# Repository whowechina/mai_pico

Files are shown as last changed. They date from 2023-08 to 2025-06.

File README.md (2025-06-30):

# Mai Pico - Maimai Style Mini Controller
[点这里可以切换到中文版](README_CN.md)

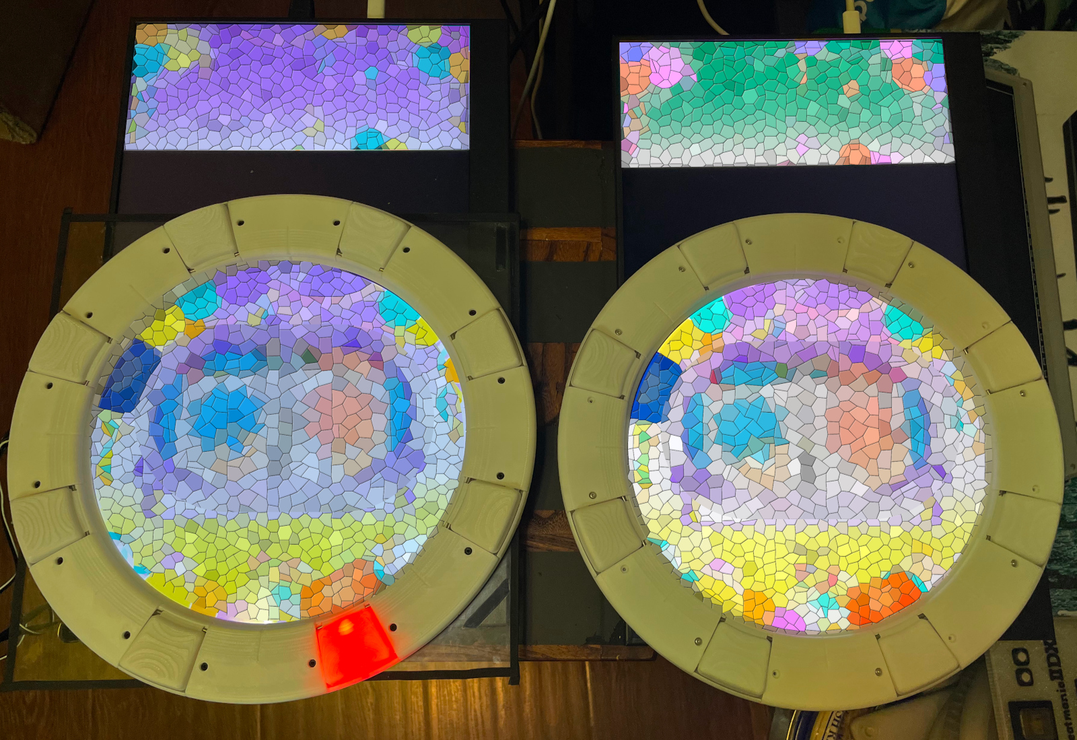
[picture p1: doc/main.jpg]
  
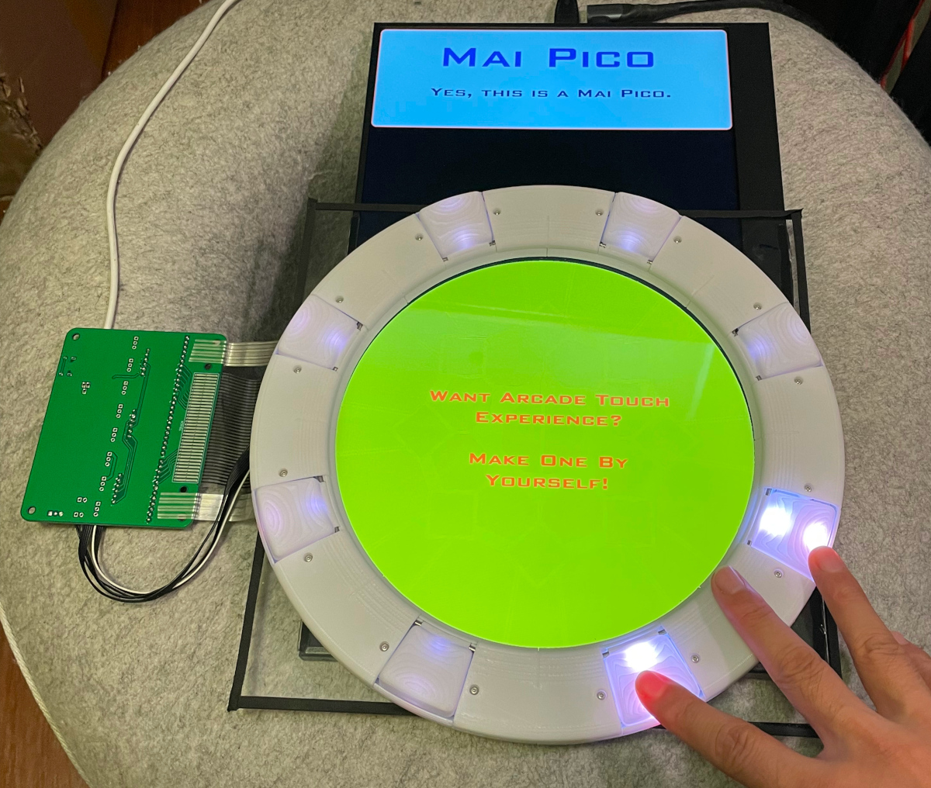
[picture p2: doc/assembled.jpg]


**Features:**
* Made with a 15.6 inch portable screen.
* Arcade-like experience.
* Dual-player is possible.
* Built-in AIME support.
* All source files open.

Thanks to many respectful guys/companies who made their tools or materials free or open source (KiCad, OnShape, InkScape, Raspberry things, JLCPCB), and also:
* RP_Silicon_KiCad: https://github.com/HeadBoffin/RP_Silicon_KiCad
* Switch_Keyboard_Kailh: https://github.com/kiswitch/keyswitch-kicad-library
* Type-C: https://github.com/ai03-2725/Type-C.pretty
* Mai2Touch: https://github.com/Sucareto/Mai2Touch

## Notes
This project is the most complex one among all my projects.
* It needs a custom etched ITO glass and a portable display.
* Heavily depends on 3D printing.
* Requires skills to solder tiny components.
* Requires many other DIY hands-on skills.
* The IO PCB is still in prototype state, it works, but the layout and connectors are not perfect. You may need to solder directly from Pi Pico's pins. I'm just too lazy to release a new version.
* I didn't design the housing, so it's your job to make it look nice and structually stable, follow your imagination and taste.

## About the License
It's CC-NC. So DIY for yourself and for your friend for free, don't make money from it. And plagiarism that doesn’t even dare to mention the original author is not acceptable. Plase note that pooling orders and group buying for raw materials is acceptable. Selling off any leftover components without profit is also acceptable.

If you're interested in buying from me or some kind of commercial use, please contact me (Discord, QQ group, Wechat group or leave your contact in issue section).

## My Discord Invitation
https://discord.gg/M8f2PPQFEA

## My Other Projects
You can check out my other cool projects.

             

* Popn Pico: https://github.com/whowechina/popn_pico
* IIDX Pico: https://github.com/whowechina/iidx_pico
* IIDX Teeny: https://github.com/whowechina/iidx_teeny
* Chu Pico: https://github.com/whowechina/chu_pico
* Mai Pico: https://github.com/whowechina/mai_pico
* Diva Pico: https://github.com/whowechina/diva_pico
* AIC Pico: https://github.com/whowechina/aic_pico
* Groove Pico: https://github.com/whowechina/groove_pico
* Geki Pico: https://github.com/whowechina/geki_pico
* Musec Pico: https://github.com/whowechina/musec_pico
* Ju Pico: https://github.com/whowechina/ju_pico
* Bishi Pico: https://github.com/whowechina/bishi_pico
* Bishi Pico: https://github.com/whowechina/nos_pico

## **Disclaimer** ##
I made this project in my personal time without any sponsorship. I will continue to improve the project. I have done my best to ensure that everything is accurate and functional, there's always a chance that mistakes may occur. I cannot be held responsible for any loss of your time or money that may result from using this open source project. Thank you for your understanding.

## Builds Gallery
Before we start, I want to encourage you with some hobbyist builds.

### **Lavide's Build**
  Lavide made a nice compact all-in-one Mai Pico cab!  
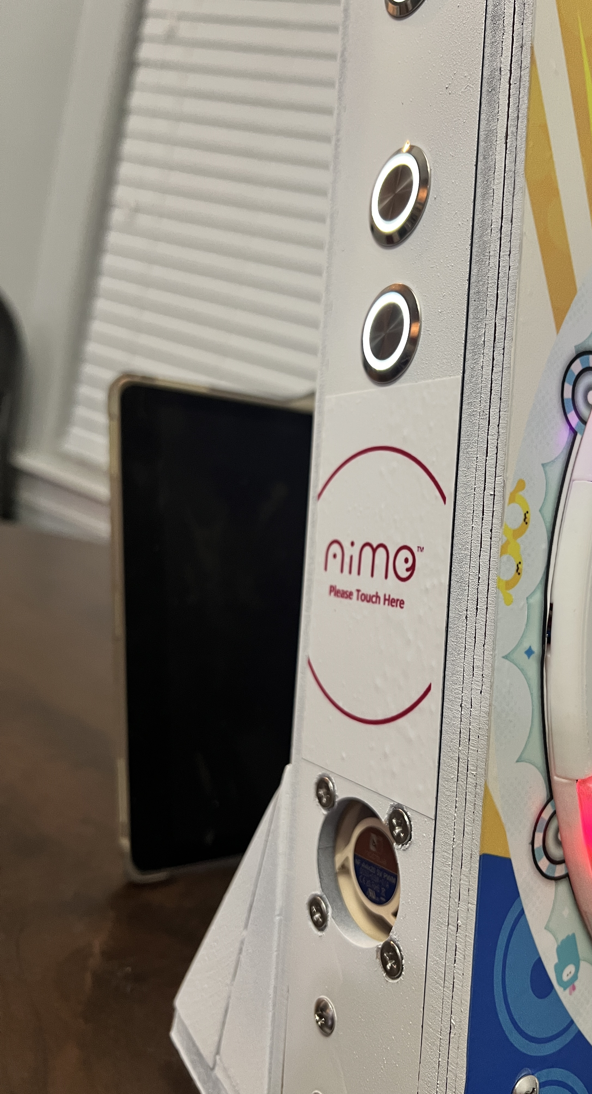
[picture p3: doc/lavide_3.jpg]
  

### **Romper's Build**
  Romper made a full-size con using Mai Pico's touch design.  
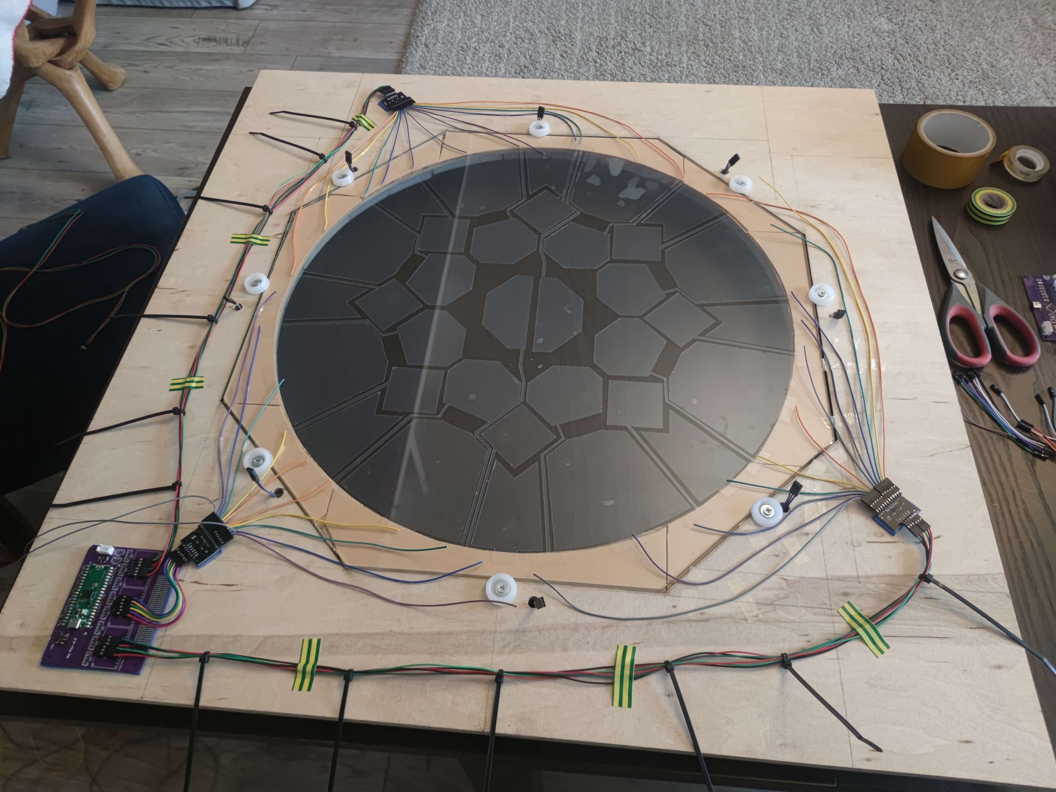
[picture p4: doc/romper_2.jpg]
    
  Check out his build guide here.  
  https://github.com/ir0nq/maimai-homemade-controller

### **imfrea's Build**
  imfrea designed a nice-looking and inexpensive acrylic housing for Mai Pico.  
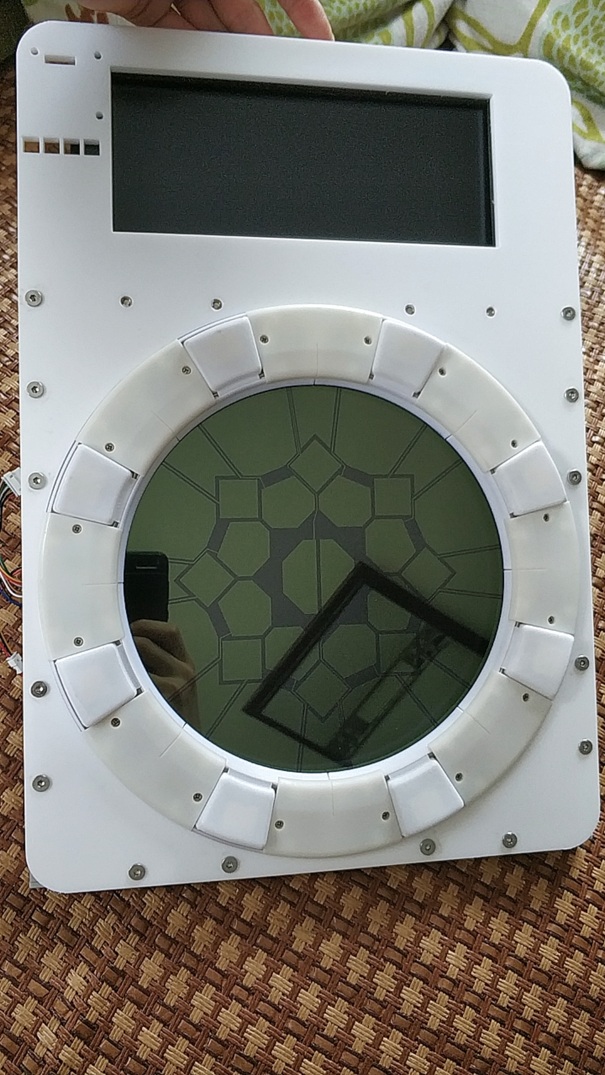
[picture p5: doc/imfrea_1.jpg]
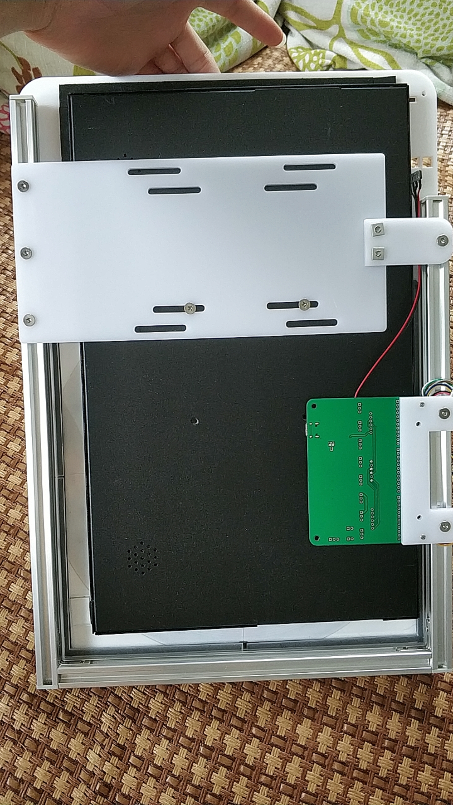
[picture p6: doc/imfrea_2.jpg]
    
  You can download the acrylic case designs from his fork of Mai Pico here.  
  https://github.com/imfrea/mai_pico

### ***IlIIllllIlIIlll's Build**
  IlIIllllIlIIlll made another nice and compact housing.  
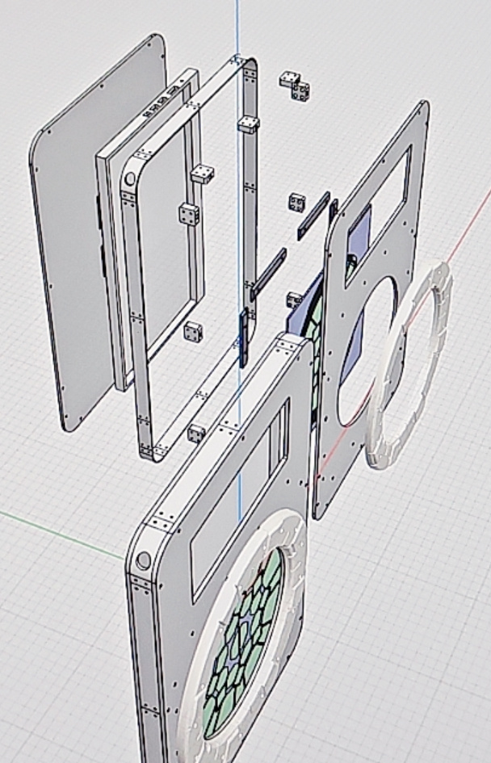
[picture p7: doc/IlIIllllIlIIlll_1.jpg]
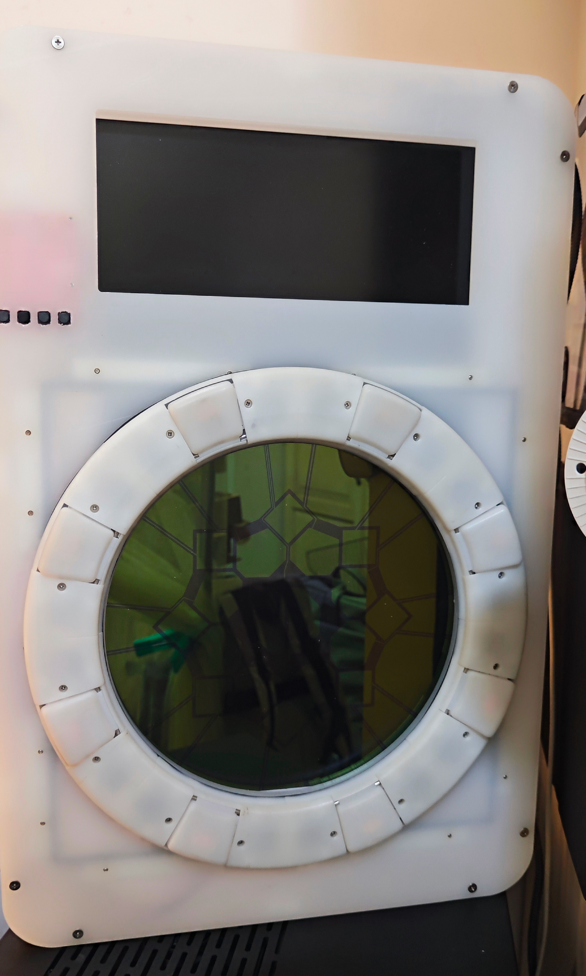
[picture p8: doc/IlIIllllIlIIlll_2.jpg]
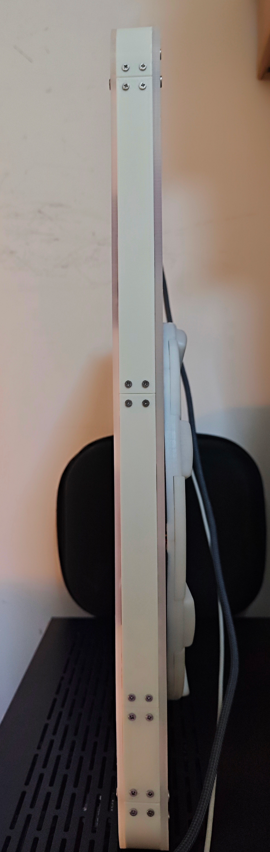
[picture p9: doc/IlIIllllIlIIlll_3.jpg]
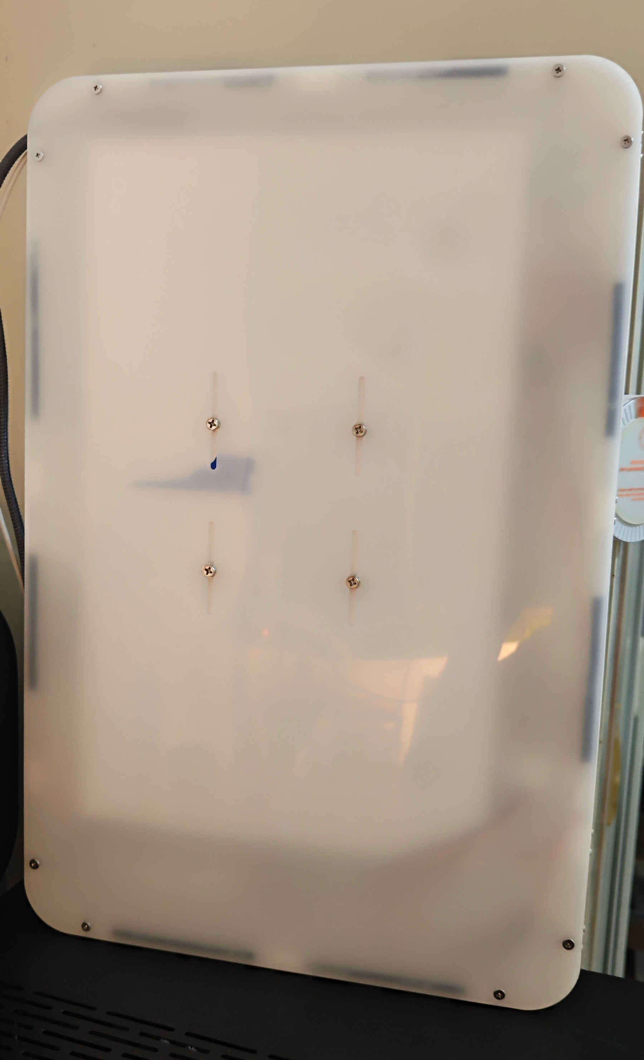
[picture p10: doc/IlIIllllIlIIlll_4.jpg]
       
  Thanks to his/her contribution, you can download the design files directly from this repository. It's located at `Production\3rdparty\IlIIllllIlIIlll_housing.zip`. The panel can be cut from PP or acrylic sheets, and other parts can be 3D printed. Plase note that this design is also not for commercial use.

## HOW TO BUILD
### PCB
* Go JLCPCB and make order with the gerber zip file (latest `Production\PCB\mai_io_v*.zip` and `Production\PCB\mai_button_v*.zip`), regular FR-4 board, 1.6mm thickness. You need 1x io PCB and 8x button PCBs for one Mai Pico con.  
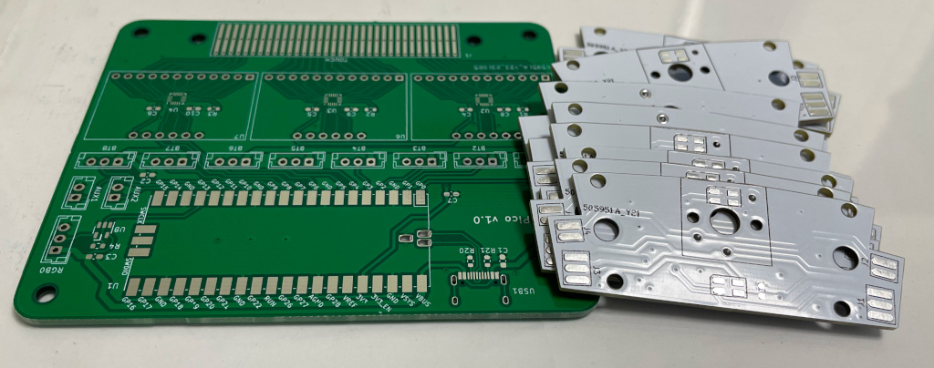
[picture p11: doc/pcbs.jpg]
  
* 1x Rasberry Pico Pi Pico or Pico W.  
  https://www.raspberrypi.com/products/raspberry-pi-pico
  Becareful of 3 pins that are at the other side, they're difficult to solder and may leave air bubbles.  
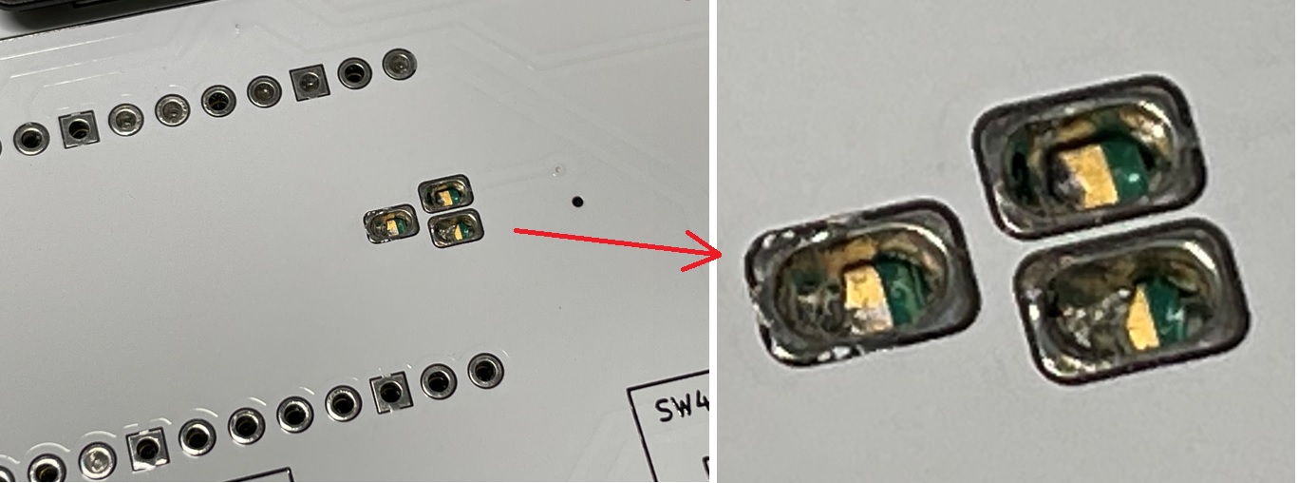
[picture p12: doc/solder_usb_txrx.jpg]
  
* 1x USB Type-C socket (918-418K2023S40001 or KH-TYPE-C-16P)
* 2x 0603 5.1kohm resistors (R20, R21) for USB. If you plan to use the native USB socket on the Pi Pico directly, then the Type-C socket and resistors can be omitted, making the soldering much simpler.
* 3x MPR121 modules, there're many types in the market, choose ones like this.  
  https://www.sparkfun.com/products/retired/9695  
  Before solder MP121 module to the main PCB board, remember to use a knife to **cut (unshort) the tiny trace that connects ADDR to the GND**. Please be careful not to cut more than necessary.  
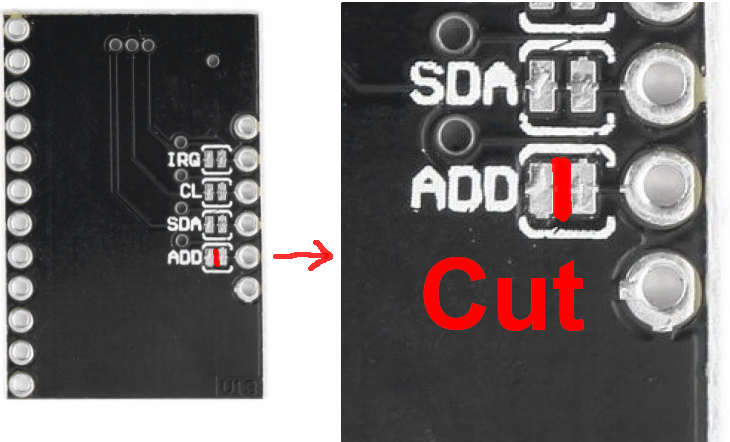
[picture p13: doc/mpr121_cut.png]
  
* Leave U5, U6, U7 area discrete components empty as we're using MPR121 module, not the chip. Please note that these components are removed in the newer version board.
* 1x SN74LV1T34DBVR (SOT-23-5) level shifter (U8), if you can't find one, just use a 0603 10ohm resistor (R4) as an alternative. In newer version board, it's removed.  
  https://www.lcsc.com/product-detail/Buffer-Driver-Transceiver_Texas-Instruments-SN74LV1T34DBVR_C100024.html
* 4x 0603 1uF (0.1~1uF all fine) capacitors (C1, C2, C3, C7), OPTIONAL, recommended. Please note that some are removed in the newer version board.
* 16x WS2812B-3528 RGB LEDs (each button needs two).
* 8x Kailh Choc v1 key switches, linear, 30gf to 45gf ones.  
  https://www.kailhswitch.com/mechanical-keyboard-switches/low-profile-key-switches/burnt-orange-switch.html
* 1x PN532 NFC module and some thin wires, only needed if you want AIME.  
  https://www.elechouse.com/product/pn532-nfc-rfid-module-v4/  
  You need to solder it to the same I2C as the MPR121 (GPIO 6 and 7).
* These are only for buttons with optical sensors.
  * 8x 0603 220ohm resistors (R1, R2, R3, R4, R5, R6, R7, R8), they're current limiter.
  * 8x 0603 5.1kohm resistors (R10, R11, R12, R13, R14, R15, R16), they're pull-up resistors. There's chance you don't need them, you can try without them first.

### ITO Glass
* Find a service to make custom etching ITO coated glass. The AutoCAD file is `Production\CAD\mai_pico_ito_v*.dwg`. Use 2mm thickness, 10-20ohm sheet resistance ITO coated glass.
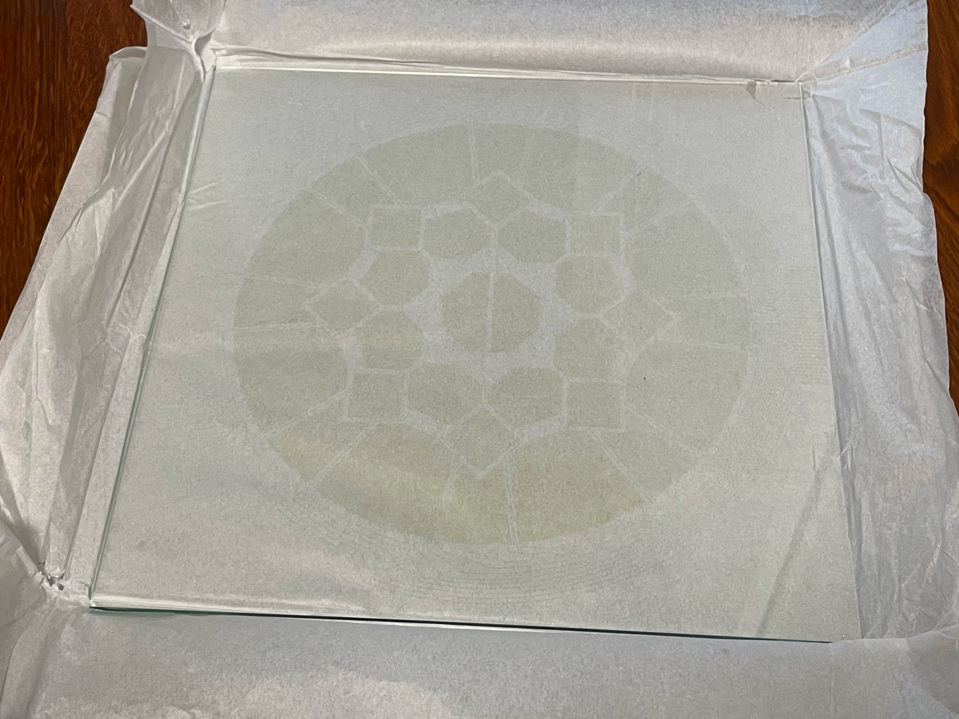
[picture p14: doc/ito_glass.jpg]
  
* The ITO coated glass is connected to the IO PCB by "zebra cable" (1.6mm pitch: 0.8mm black part and 0.8mm clear part). A silicon heater head at 200°C is used to stick the zebra cable to the gold finger part of PCB and ITO coated glass. The formal name of this cable is "Heat Seal Connector".  
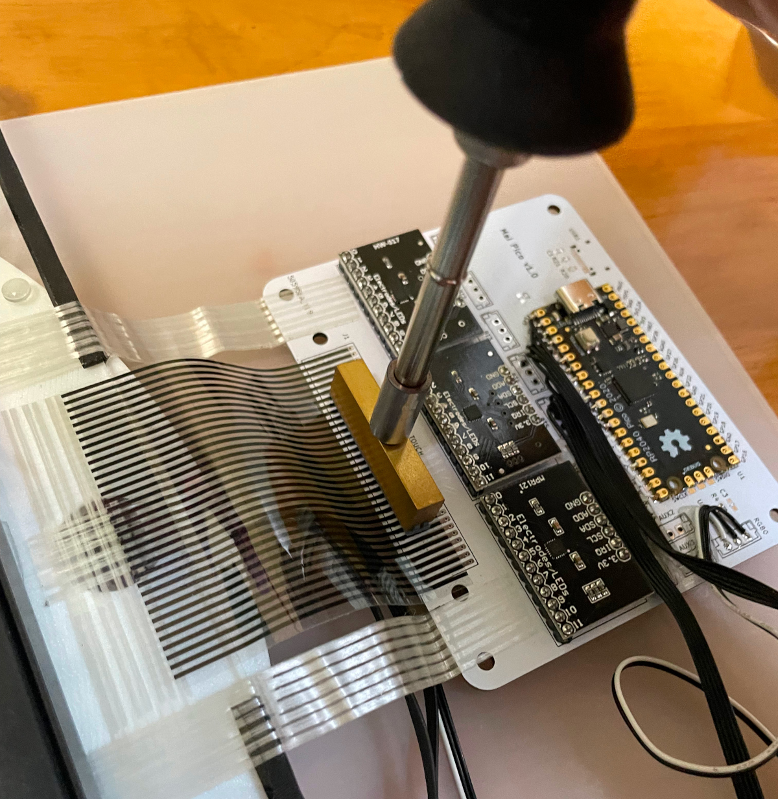
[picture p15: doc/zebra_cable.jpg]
  
* Custom ITO coated glass is relatively expensive, but ours is small, so it's not like arcade-size expensive. This is the shop I ordered the ITO glass. The minimal batch is around 5 pieces. But they provide service only in China as far as I know.  
  https://shop378788148.taobao.com/?spm=2013.1.1000126.2.305e16c4LFf1GW

### Button Ring
* Print out the 8x set of base, link, button and cover from `Production\3DPrint\mai_*.stl`.
* Buy 8x 2mm (diameter) * 40mm (length) steel shafts, they're used as the button hinge.
* Here's how to assemble them, hinge shaft and components on PCB are not shown in this rendered image.  
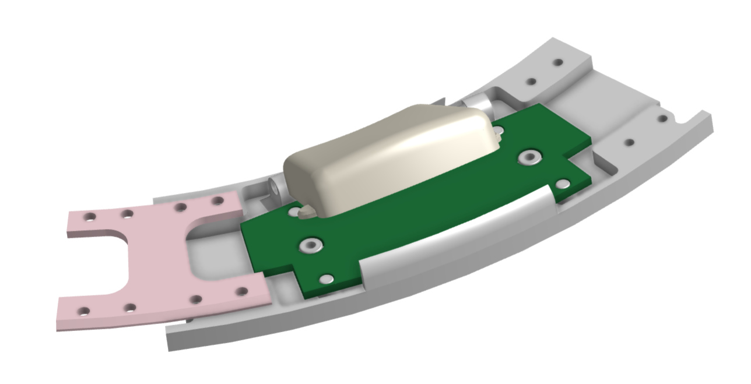
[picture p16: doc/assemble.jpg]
  
* Here's how I assembled the ring. Please note that wiring for the button switches is missing in these pictures.
  * All discrete components ready.  
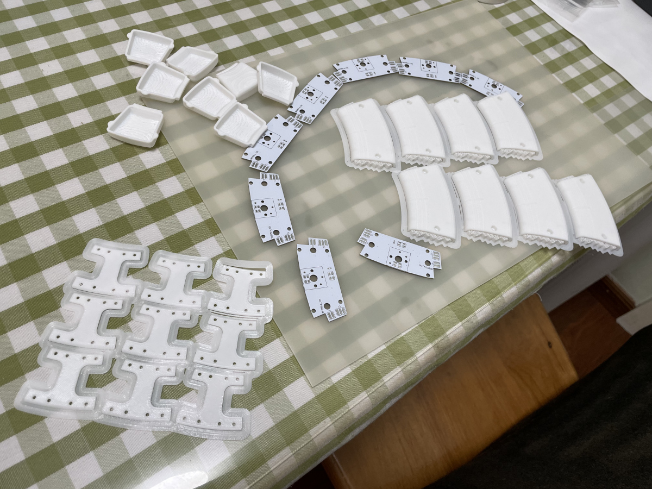
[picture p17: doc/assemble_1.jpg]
    
  * Solder the button PCB first.  
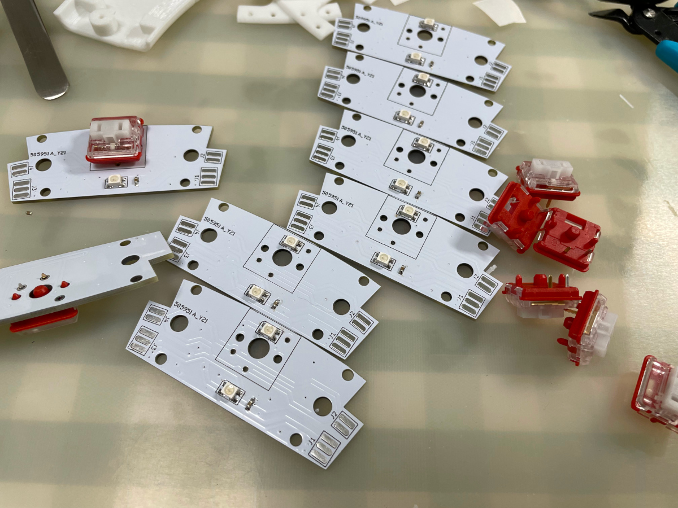
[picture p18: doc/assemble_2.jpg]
    
  * Button PCBs are daisy-chained using short and soft 3-wire cable, they're G, IN/OUT, V (GND, Signal In/Out and VCC respectively). RGB signal goes in from "IN" and goes out to the next LED through "OUT". The "Btn" button signal pins are not soldered yet, you can later wire them. Don't worry about the order of button GPIOs, because they can be remapped through command line interface.    
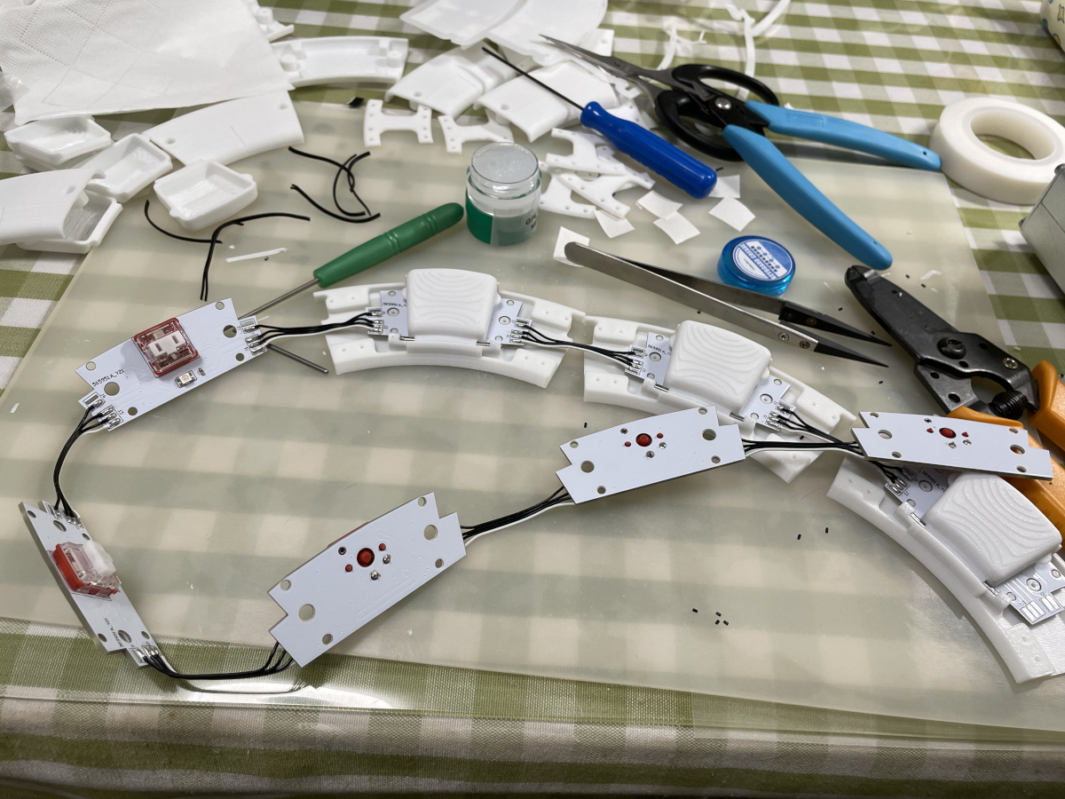
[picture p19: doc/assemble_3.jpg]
    
  * You need 3M5423 UHMW film tape (or similar hard and super-smooth PTFE tape with 0.2-0.3 thickness). It is to lubricate the button surface that touches the keyswitch.  
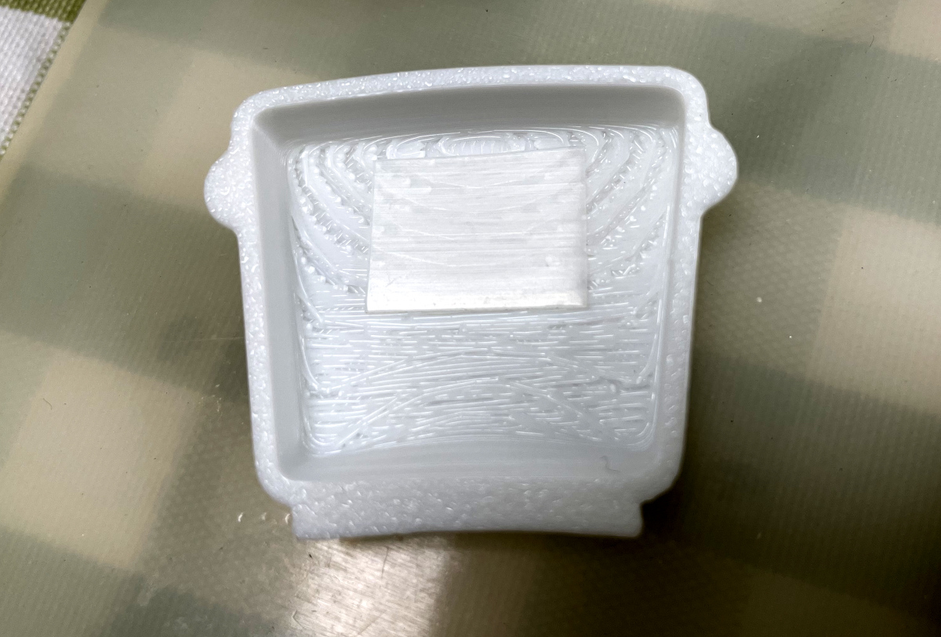
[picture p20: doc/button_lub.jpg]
    
  * Assemble the 3D printed parts together with the PCBs.  
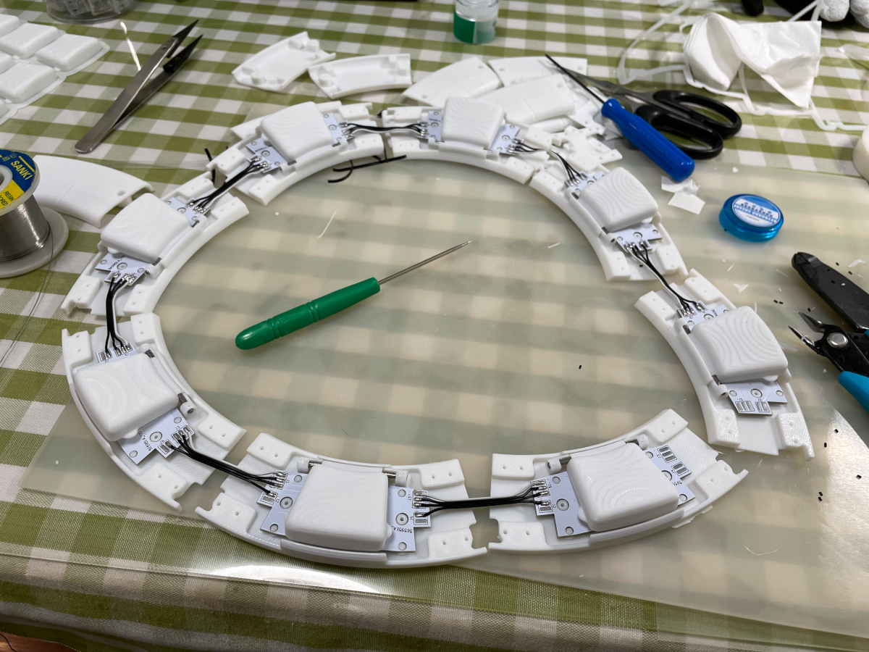
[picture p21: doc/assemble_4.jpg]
    
  * Use shaft to expand the support holes a little bit, and apply some keyboard switch lubricant such as Krytox 205G0 to make the shaft super smooth.  
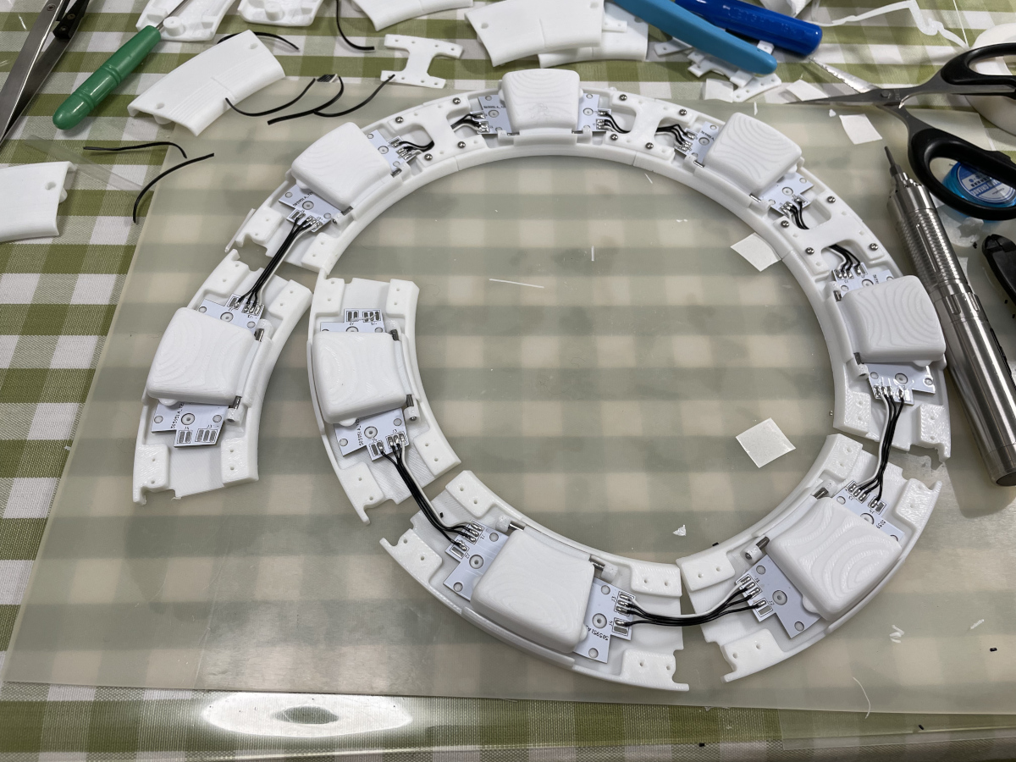
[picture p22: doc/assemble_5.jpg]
    
  * Each `link` needs 8x M2*4mm screws to connect two `base`s together.  
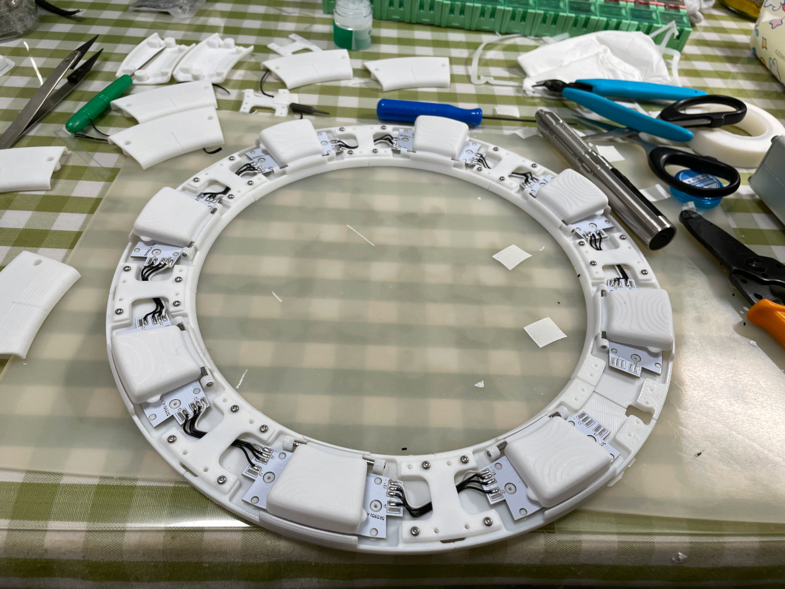
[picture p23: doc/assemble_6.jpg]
    
  * Install the cover, each needs 2x M2*5mm screws.  
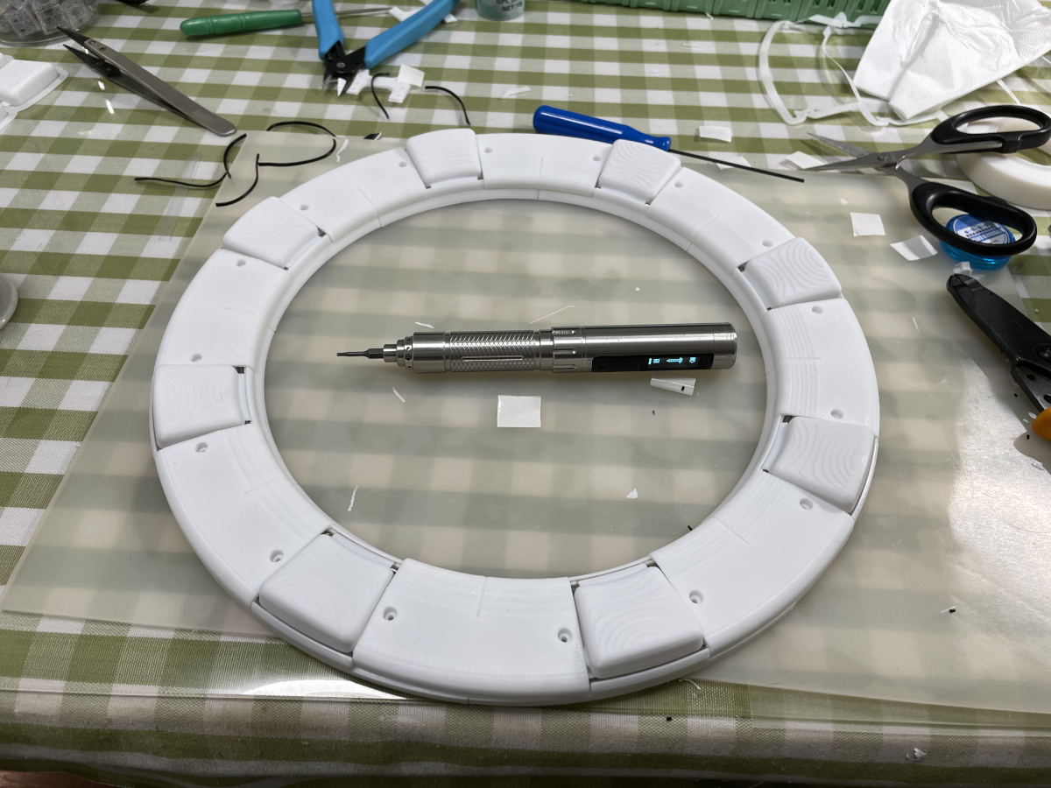
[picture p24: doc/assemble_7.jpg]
    

### Portable Display
  * Resolution: 1920*1080, size: 15.6inch, refresh rate: 120Hz (recommended) or 60Hz, built-in speakers.
  * They're easy to find. Choose cheap or even tiny-flawed ones, they're much cheaper and work just fine.
  * There're 2 types of driver board, one is micro-HDMI only and the other supports type-C display (for convenient Nintendo Switch connection). They're both OK.  
  https://www.amazon.com/s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

### Glue Things Together
  * I use 3M VHB tape (0.5mm or 1mm thickness) to stick the button ring, the ITO glass and the monitor together.
  * Only use a little tape, I use 4 small pieces to stick ITO glass to the display and another 4 small pieces to stick button ring to the ITO glass.
  * Don't apply the tape on the traces of the ITO glass, you can see the traces or pads at certain angle.

### Housing
  * It's your job to design it and make it look nice.

### Firmware
* UF2 file is in `Production\Firmware` folder.
* For the new build, hold the BOOTSEL button while connect the USB to a PC, there will be a disk named "RPI-RP2" showed up. Drag the UF2 firmware binary file into it. That's it.
* LED and Touch protocols are implemented following Sucareto's research at https://github.com/Sucareto/Mai2Touch.
* It has a command line to do configuration. You can use this Web Serial Terminal to connect to the USB serial port of the Mai Pico. (`?` to display help message.)  
  https://googlechromelabs.github.io/serial-terminal/  
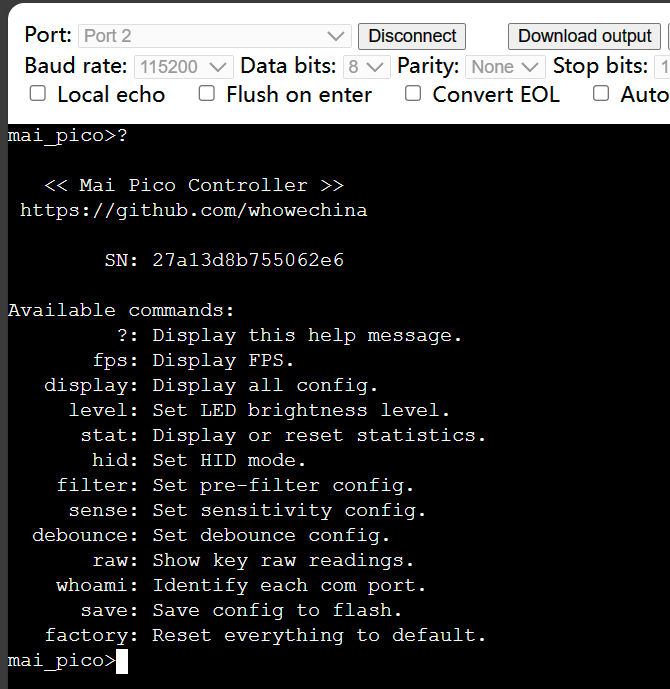
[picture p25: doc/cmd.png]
  
   * Please note that when you click "Connect" button, you'll actually see the name of each port.  
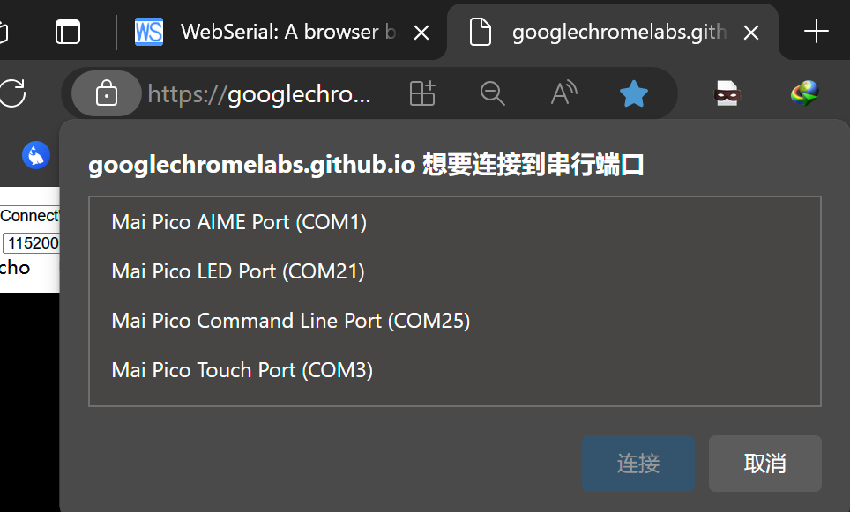
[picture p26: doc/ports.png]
   
* Button GPIOs can be remapped using `gpio` command. Firmware supports 8 main buttons on the ring and 4 auxiliary buttons (Test, Service, Navigate and Coin).
* Touch keys can be remapped using `touch` command. For people who's using Mai Pico to drive a custom ITO film or a ITO glass, this command will be very useful. For example:
  * `touch` with no parameter is to detect touched keys.
  * `touch 1 9 E6` is to set the second MPR121's electrode 9 to key "E6". Key name of "XX" means "Not Connected".
* Daisy chained RGB LED numbers for each button can be assigned using `rgb` command.
* LED brightness can be adjusted by `level` command.
* There are MPR121 parameter tuning and sensitive settings, explore them yourself.
* It implements 3 COM ports, one is for command line and the other two are for LED and Touch. By issuing `whoami` to the command line, each COM port will print their identities.
* Button signal is sent to the host by HID Joystick or HID NKRO (keyboard). There're two set of NKRO keymaps, use `hid <joy|key1|key2>` to switch between them. In NKRO mode, key mappings are:
  * key1: `WEDCXZAQ`-Ring Buttons, `3`-Select
  * key2 (Numpad): `89632147`-Ring Buttons, `*`-Select
  * Above two sets both have: `F1`-Test `F2`-Service `F3`-Coin
* `factory` to reset to default. When there's a firmware update, the old configuration may become corrupted, you can reset configuration, then re-plug the controller.

## CAD Source File
I'm using OnShape free subscription. It's powerful but it can't archive original designs to local, so I can only share the link here. STL/DXF/DWG files are exported from this online document.  
https://cad.onshape.com/documents/d8b39d27c9cb7990d9ce4d46/w/2c1baa71e391bfd1246f122b/e/f87f0f1c373fe2186ddc5c9c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

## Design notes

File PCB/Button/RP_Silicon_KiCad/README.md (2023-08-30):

# RP\_Silicon\_KiCad
KiCad resources to help create designs using the Raspberry Pi MCUs

This first upload is extracted unaltered from:

* [https://datasheets.raspberrypi.org/pico/RPi-Pico-R3-PUBLIC-20200119.zip](https://datasheets.raspberrypi.org/pico/RPi-Pico-R3-PUBLIC-20200119.zip)
* [https://datasheets.raspberrypi.org/pico/RPi-Pico-R3-PUBLIC-20200119.zip](https://datasheets.raspberrypi.org/pico/RPi-Pico-R3-PUBLIC-20200119.zip)

This provides the Pico and the RP2040 library & footprint files respectively.

Keep these files out of the KiCad directories so they don't get overwritten by any updates. I have the KiCadLibraries in my Documents folder so that macOS will iCloud sync automagically for me. You can do similar on other OS's.

Set the location of this folder in both the Manage Symbol Libraries and the Manage Footprint Libraries menu options from the Preferences menu.

If you are not sure about this, see [Install.md](Install.md)

These libraries may be included in the main set of KiCad libraries at a later point, at which time I'll look to see if there is a need to maintain this repro.

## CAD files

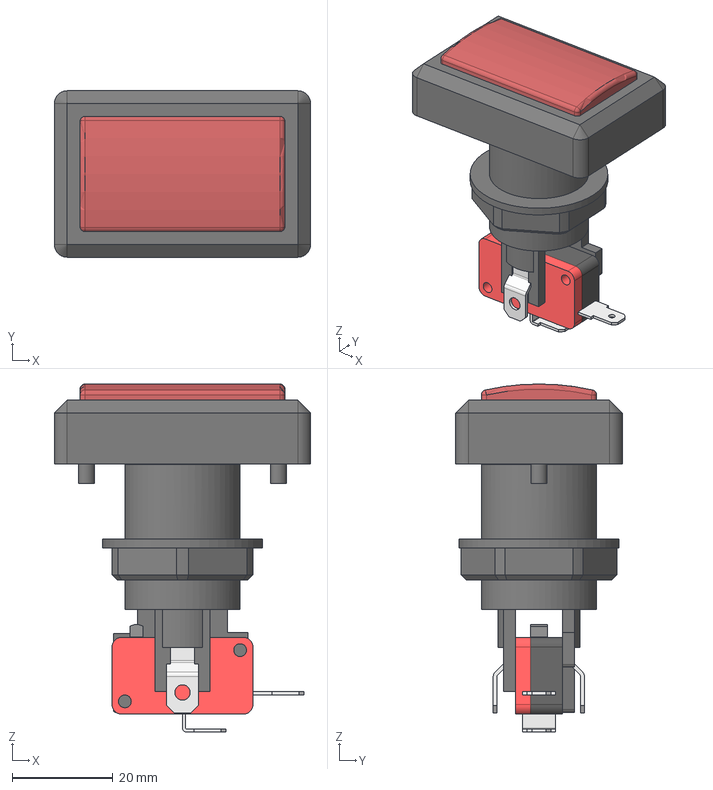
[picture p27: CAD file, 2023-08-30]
PCB/Button/3dmodels/Credit Button Assy (Groovy).step
50.8 x 33.0 x 69.0 mm
Button
Nut
Switch

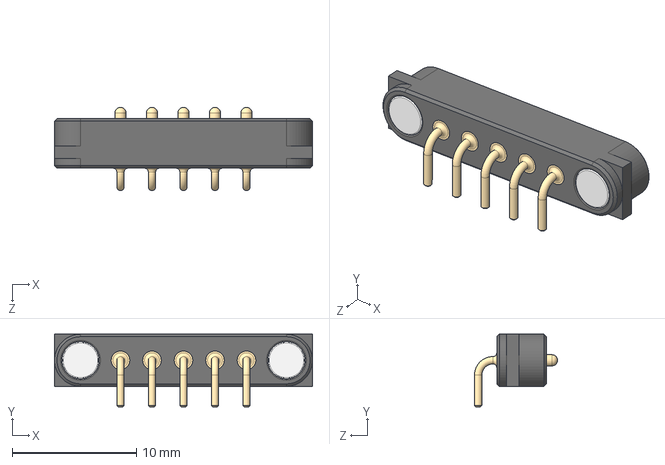
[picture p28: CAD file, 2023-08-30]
PCB/Button/3dmodels/Magnetic Pogo Connector 5 Pin (Type 4).STEP
20.8 x 5.85 x 6.70 mm

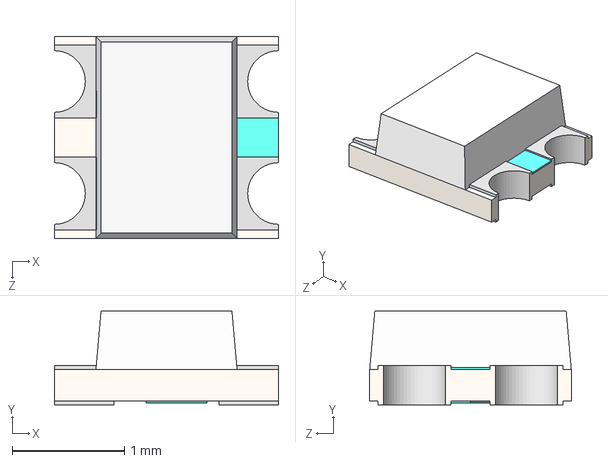
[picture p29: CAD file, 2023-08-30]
PCB/IO/3dmodels/WS2812-0807.STEP
2.00 x 0.835 x 1.80 mm

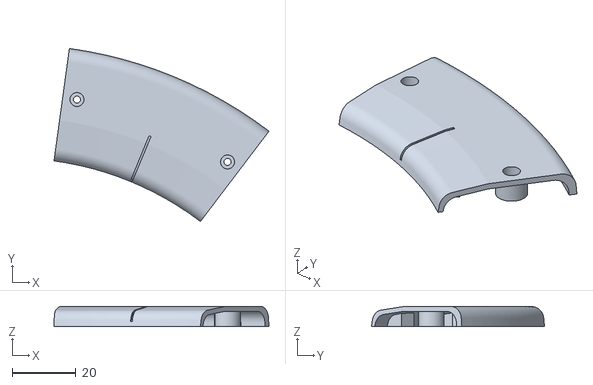
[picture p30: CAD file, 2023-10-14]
Production/3DPrint/mai_cover.stl
67.7 x 54.5 x 6.30

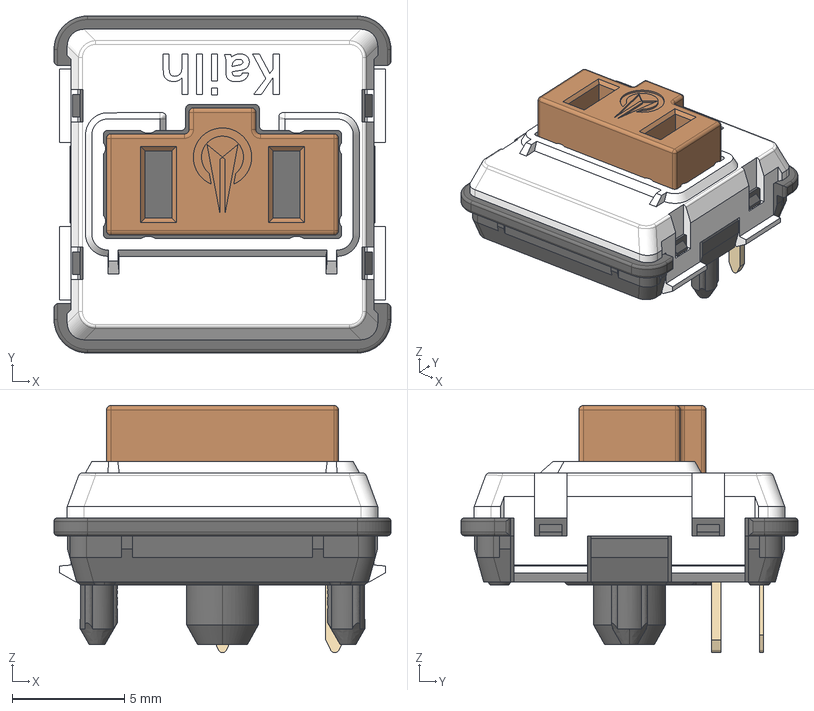
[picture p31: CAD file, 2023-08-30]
PCB/Button/3dmodels/SW_Kailh_Choc_V1.stp
15.0 x 15.0 x 11.0 mm

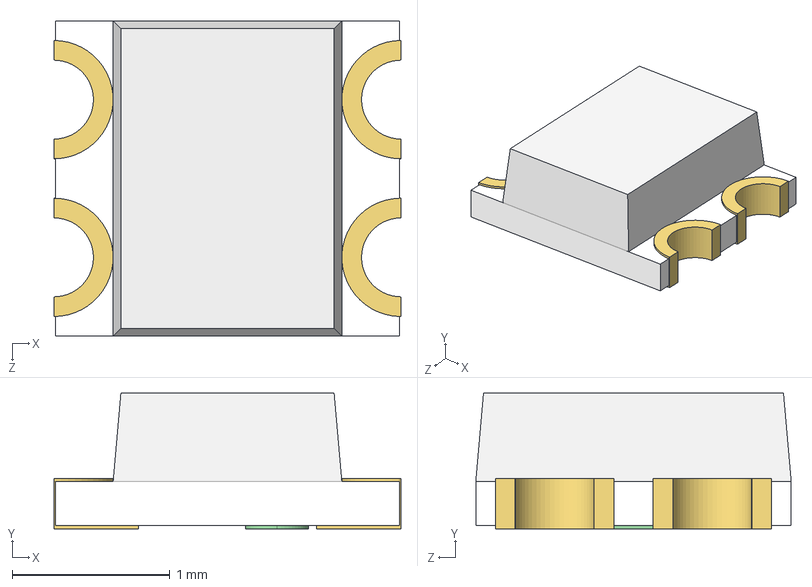
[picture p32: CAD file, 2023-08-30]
PCB/IO/3dmodels/WS2812-2020.STEP
2.20 x 0.86 x 2.00 mm

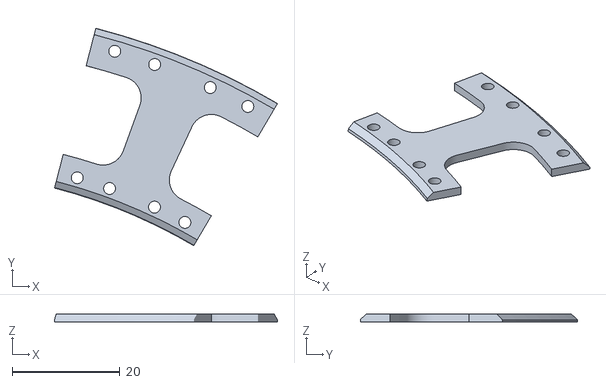
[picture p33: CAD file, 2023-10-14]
Production/3DPrint/mai_link.stl
41.4 x 40.4 x 1.50

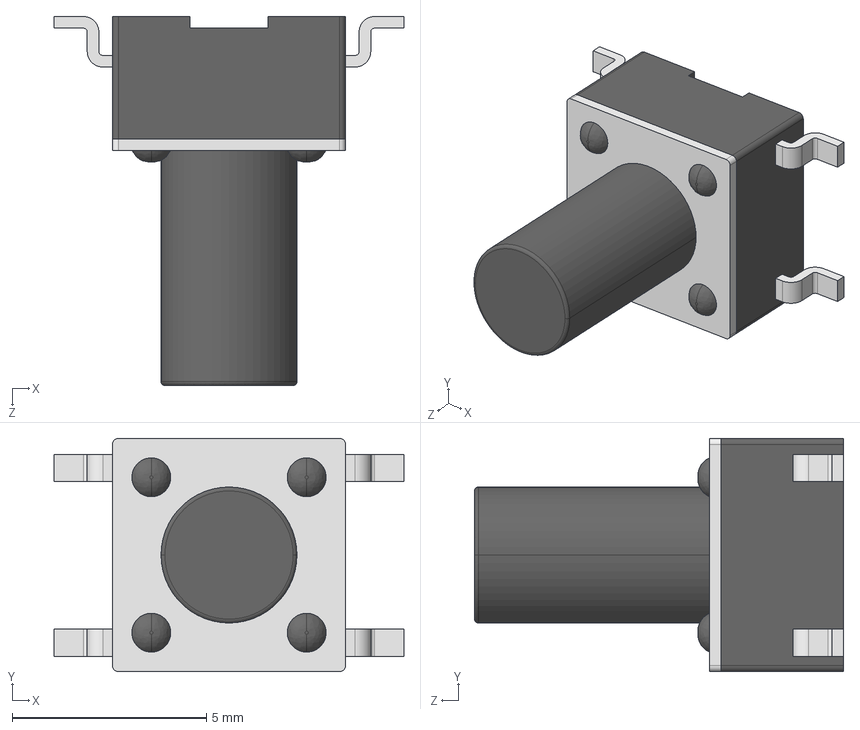
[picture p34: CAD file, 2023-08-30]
PCB/Button/3dmodels/User Library-PTS645SL95SMTR92-LFS.STEP
9.00 x 6.00 x 9.50 mm

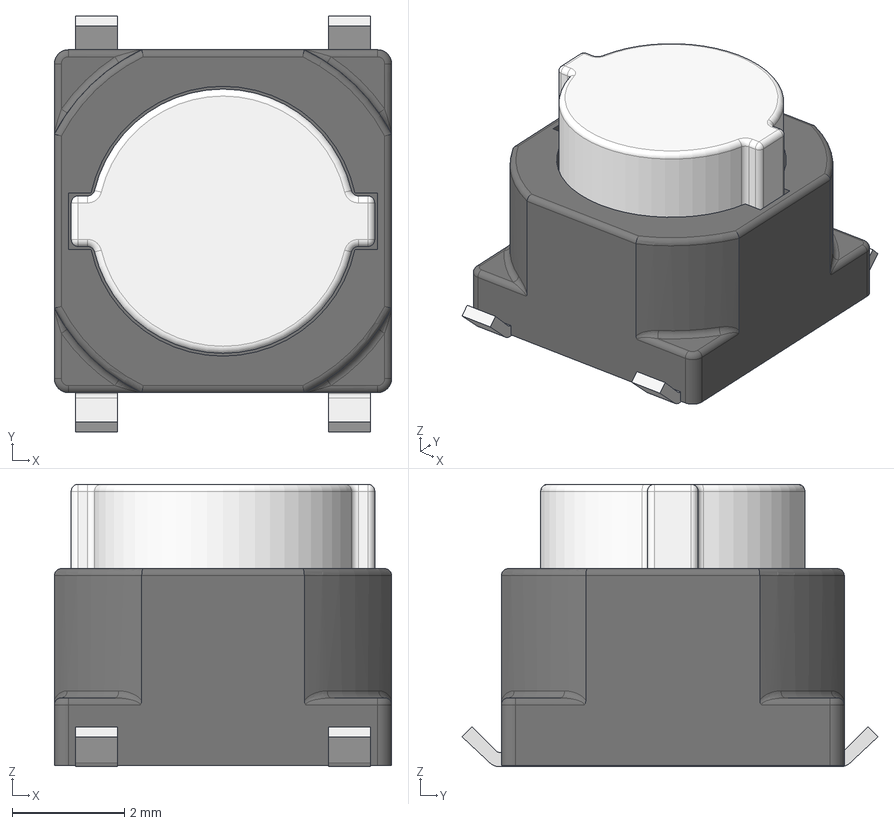
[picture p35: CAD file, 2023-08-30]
PCB/IO/3dmodels/EVQ-P1D05M.stp
6.00 x 7.40 x 5.03 mm

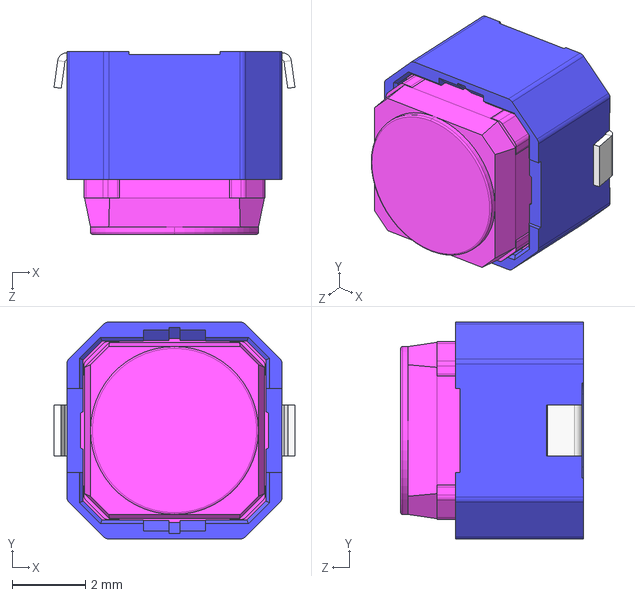
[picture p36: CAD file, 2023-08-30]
PCB/Button/3dmodels/SKPMAM.STEP
6.60 x 5.94 x 5.00 mm

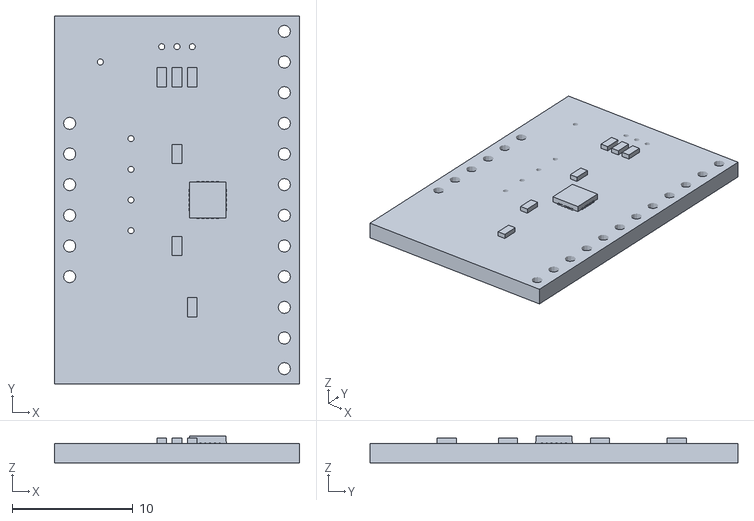
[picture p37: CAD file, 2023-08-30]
PCB/IO/3dmodels/mpr121_breakout_v13.stl
20.3 x 30.5 x 2.20

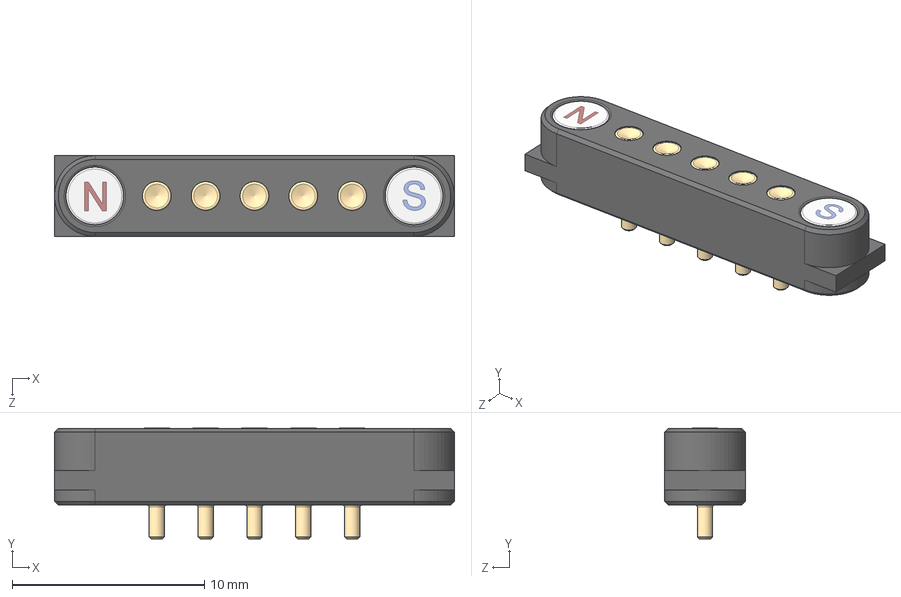
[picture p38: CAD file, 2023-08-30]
PCB/IO/3dmodels/Magnetic Pogo Connector 5 Pin (Type 1).STEP
20.8 x 5.75 x 4.20 mm

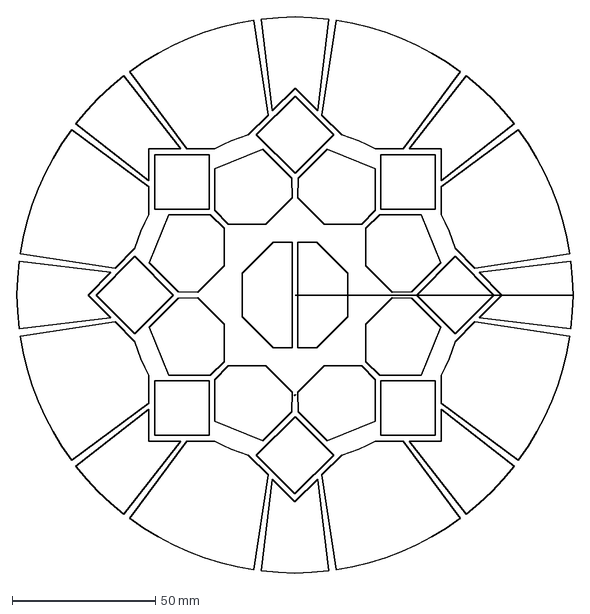
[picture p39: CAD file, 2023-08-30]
cad/maimai_touch.dxf
194.5 x 194.5 mm

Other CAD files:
PCB/Button/3dmodels/iidx_keycap_main_step.stp
PCB/IO/3dmodels/iidx_keycap_main_step.stp
Production/CAD/mai_pico_ito_v1.dwg
cad/maimai_touch v8.dxf
PCB/Button/3dmodels/J 2835.step
PCB/Button/3dmodels/Kailh LP Choc PC Keycap.step
PCB/Button/3dmodels/Magnetic Pogo Connector 5 Pin (M) - 副本.STEP
PCB/Button/3dmodels/Magnetic Pogo Connector 5 Pin (Type 2).STEP
PCB/Button/3dmodels/Magnetic Pogo Connector 5 Pin (Type 3).STEP
PCB/Button/3dmodels/Part Studio - pcb.step
PCB/Button/3dmodels/SMD WS2812B-3535.step
PCB/Button/3dmodels/SW_Hotswap_Kailh_Choc_V1.stp
PCB/Button/3dmodels/SW_Hotswap_Kailh_MX.stp
PCB/Button/3dmodels/Tact Switch 4.5mm SMT.step
PCB/Button/3dmodels/User Library-WS2812-2020.step
PCB/Button/3dmodels/User Library-WS2812-4020.step
PCB/Button/3dmodels/User Library-pj-393-8.STEP
PCB/Button/3dmodels/WS2812B.step
PCB/Button/3dmodels/mpr121_breakout_v13.blend
PCB/IO/3dmodels/J 2835.step
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

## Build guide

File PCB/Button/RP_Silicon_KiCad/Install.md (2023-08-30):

# Install KiCad libraries

## Manage Symbol Libraries

Accessed from the Preferences menu, add a new line with the +, give it a name and use the folder icon to point to the directory/folder where you have KiCadLibraries.

Manage Symbol Libraries screen shot


## Manage Footprint Libraries

Ditto! Accessed from the Preferences menu, add a new line with the +, give it a name and use the folder icon to point to the directory/folder where you have KiCadLibraries.

Manage Footprint Libraries screen shot


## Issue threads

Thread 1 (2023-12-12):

关于盖板螺丝

laognf95, 2023-12-12:
M2*5mm的自攻螺丝。。 只能堪堪露出尖头，锁不上盖板。。

我这边在嘉立创三维猴打印的按键，用M2*8mm的螺丝可以稳定锁上

whowechina, 2023-12-12:
Those should be regular machine screws, not self-tapping screws.
要用普通螺丝，不要用自攻。打印材料很软，普通螺丝就能轻松“刻”出螺纹。

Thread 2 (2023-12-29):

3D模型部分区域壁厚太薄

WYH2004-MC, 2023-12-29:
部分壁厚太薄了，打印精度不够可能会有问题
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

whowechina, 2023-12-29:
I'm not going to change for following reasons.
* They work well on Bambu printers.
* I don't have other printer system to verify.
* Source CAD files are open, one can finetune based on his/her(hopefully) own results.

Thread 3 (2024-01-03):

s?g?tools.ini config help!

Linkcore4423, 2024-01-03:
Can anyone tell me how to configure s.ini? I am trying to write UF2 firmware, and a device named "Mai Pico" also appears in Windows. How can I configure my ini file?

The current configuration is as follows:

[vfs]
amfs=amfs
appdata=appdata
option=option

[dns]
default=16.0.0.140

[io4]
enable=0

[button]
enable=0

[aime]
enable=1

[jvs]
enable=0

The current symptom is getting stuck in Aime Check.
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

Becods, 2024-01-04:
This problem is not caused by mai_pico.

You should ask the right questions in the right place.

whowechina, 2024-01-05:
Yeah, it's not ok to talk things like this here.

Closed 2024-01-05.

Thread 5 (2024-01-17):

[Bug Report] Stuck on aime check when using io4

Becods, 2024-01-17:
### Bug Description

Stuck on aime check when using io4
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

### Steps to reproduce

1. Set segatools' io4 emulation to disable
```
[io4]
enable=0
```
2. Plug in the rp2040 with the burned-in firmware from the `Production`
3. Set hid to joy
4. Launching the game

### Other

I tried to use [lkick-io4](https://github.com/XxLittleCxX/lkick-io4) and it works everything perfectly

But I had to use multiple boards to replace what would have been done with a single board

whowechina, 2024-01-17:
Sounds not an io4 problem. Use Windows Joystick tool from control panel to check if io4 hid is working properlly.
So far, mai pico has not integrated aime (aic pico).

Becods, 2024-01-18:
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

I've tried to connect the card reader but the problem persists

whowechina, 2024-01-18:
Thank you for the report. The hid looks fine.
I'm afraid I can't do anything, unless it's a very specific hid or protocol issue. It's not ok to talk or help with arcade data related things here.

whowechina, 2024-02-25:
This is actually a valid issue, so I reopened it. Why the IO4 has impact to AIME server check is still a mystery to me.

whowechina, 2024-02-25:
Turned out it has something to do with io4 hid output. Now it's fixed. Thank you. @Becods

Closed 2024-02-25.

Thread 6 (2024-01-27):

ITO玻璃可否倒角？

imfrea, 2024-01-27:
您好，ITO玻璃的四角能否做成类似于官方原装触屏那种样式？
正方形的四角锋利且占据一定空间，如果能剪裁掉或将更加完美（不知道这是否会增加成本）
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

whowechina, 2024-01-28:
爱好者只买几块的情况下，厂商可能不大愿意麻烦，除非多加点钱。技术上说，只要不切到走线怎么弄都可以。
用醋酸胶带包裹边缘也是一个不错的选项，我的部分截图里可以看到。

Closed 2024-01-28.

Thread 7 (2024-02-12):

您好。。。关于mai pico

CY202032, 2024-02-12:
mai2led已经更新，您的项目可否更新一下呢？
按键部分无法投币，
灯光部分还有一些不足，呼吸效果，渐变效果都没有。
如果补全这个工程真的就太棒了

whowechina, 2024-02-12:
呼吸和渐变，我没见过实物或者资料，所以不知道怎么实现。
如果有这些效果的视频（最好不是在玩的时候，而是在 demo 的时候），那就很容易做了。

CY202032, 2024-02-12:
这个呼吸渐变是在无人游玩的时候，播放demogame时候的灯光效果，有联系方式么？探讨一番可否？
mai2led是已经实现这个功能了

whowechina, 2024-02-12:
我在 Discord C&S 活动，过年回老家了，回杭后加灯光 Fade In/Out。
另外，帮忙把 issue 标题写具体一些，读起来友好。

whowechina, 2024-02-12:
我记得投币按钮也做进去了，只是没有改 pcb，这个板子画的很随意，草稿可用后就没有优化，从 pico 直接引线即可。

whowechina, 2024-02-12:
![Uploading Picsart_24-02-12_21-32-17-960.jpg…]()

whowechina, 2024-02-12:
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

CY202032, 2024-02-12:
mai2的投币是滑块，并不是按钮，实现起来比较麻烦。。。

namespace component {
    namespace io4_usb {
        output_t output_data;
        output_keyboard_t output_keyboard_data;
        static bool coin_triggered = false;
        TaskHandle_t h_add_coin;
        [[noreturn]] static void add_coin_task(void *arg) {
            gpio_init(22);
            gpio_set_dir(22, GPIO_IN);
            gpio_pull_up(22);
            while (true) {

                    bool button_state = !gpio_get(22);
                    if (!coin_triggered && button_state) {
                        output_data.coin[0].count++;
                        printf("coin_task: inserted coin\n");
                        coin_triggered = true;
                    } else if (coin_triggered && !button_state) {
                        coin_triggered = false;
                    }
                vTaskDelay(200 / configTICK_RATE_HZ);

            }
        }
        void usb_init() {
            gpio_init(22);
            gpio_set_dir(22, GPIO_OUT);
            gpio_put(22, 0);
            xTaskCreate(add_coin_task, "test_coin", 4096, nullptr, 5, &h_add_coin);

        }

whowechina, 2024-02-12:
好的，这个简单。

whowechina, 2024-02-13:
> mai2的投币是滑块，并不是按钮，实现起来比较麻烦。。。
```
     output_data.coin[0].count++;
```
它的投币怎么“消耗”，也就是 `count--`  的逻辑在哪里？
另外你引用的 `io4 output_data` 的结构体帮忙在这里贴一下。  

CY202032, 2024-02-13:
不好意思啊，我这个东西也是个半成品逻辑很混乱，理论上是chutes[2]，我也不是很理解这个东西。。关于这个东西我也是很费解，所以代码都是乱七八糟的，本身也不是我写的。。读卡器功能你也可以加入到工程中就非常完善了。这个userid是我WX号，方便交流可以加一下，本身我对C不是很了解。
#include "stdinclude.h"

namespace component {
    namespace io4_usb {
        enum class coin_condition_t: uint8_t {
            normal = 0x0,
            jam=0x1,
            disconnect=0x2,
            busy=0x3
        };

        struct coin_data_t {
            coin_condition_t condition;
            uint8_t count;
        } __attribute((packed));

        struct output_t {
            int16_t analog[8];
            int16_t rotary[4];
            // 10bit be number
            coin_data_t coin[2];
            uint16_t switches[2];
            uint8_t system_status;
            uint8_t usb_status;
            uint8_t _unused[29];
        } __attribute((packed)) ;

        enum cmd_t : uint8_t {
            SET_COMM_TIMEOUT = 0x01,
            SET_SAMPLING_COUNT = 0x02,
            CLEAR_BOARD_STATUS = 0x03,
            SET_GENERAL_OUTPUT = 0x04,
            SET_PWM_OUTPUT = 0x05,
            UPDATE_FIRMWARE = 0x85,
        };

        struct input_t {
            uint8_t report_id;
            cmd_t cmd;
            uint8_t payload[62];
        } __attribute((packed));

        // keyboard data
        struct output_keyboard_t {
            uint8_t modifier;
            uint8_t reserved;
            uint8_t keycodes[6];
        } __attribute((packed));

        void usb_init();

        [[noreturn]] void tud(void *pVoid);

        void process_data(const input_t *data);
    }
}

#include "stdinclude.h"

#include "config.h"
#include "Effects/Marquee.hpp"
#include "hardware/adc.h"
#include "stdinclude.h"

#include "hardware/adc.h"
#include "pico/bootrom.h"
#include "pico/error.h"
#include "../analogRead/analog_read.h"
#include "scancode.h"

namespace component {
    namespace io4_usb {
        output_t output_data;
        output_keyboard_t output_keyboard_data;
        static bool coin_triggered = false;
        TaskHandle_t h_add_coin;
        [[noreturn]] static void add_coin_task(void *arg) {
            gpio_init(22);
            gpio_set_dir(22, GPIO_IN);
            gpio_pull_up(22);
            while (true) {

                    bool button_state = !gpio_get(22);
                    if (!coin_triggered && button_state) {
                        output_data.coin[0].count++;
                        printf("coin_task: inserted coin\n");
                        coin_triggered = true;
                    } else if (coin_triggered && !button_state) {
                        coin_triggered = false;
                    }
                vTaskDelay(200 / configTICK_RATE_HZ);

            }
        }
        void usb_init() {
            gpio_init(22);
            gpio_set_dir(22, GPIO_OUT);
            gpio_put(22, 0);

            xTaskCreate(tud, "tud", 2048, NULL, 10, NULL);
            xTaskCreate(add_coin_task, "test_coin", 4096, nullptr, 5, &h_add_coin);

        }

        [[noreturn]] void tud(void *pVoid) {
            using namespace component::config;
            uint8_t last_mode = 0;

            auto aime_led = aime_reader::getController();
            std::vector<PicoLed::Color> rainbow_palette;
            rainbow_palette.push_back(PicoLed::RGB(255, 0, 0));
            rainbow_palette.push_back(PicoLed::RGB(255, 255, 0));
            rainbow_palette.push_back(PicoLed::RGB(0, 255, 0));
            rainbow_palette.push_back(PicoLed::RGB(0, 255, 255));
            rainbow_palette.push_back(PicoLed::RGB(0, 0, 255));
            rainbow_palette.push_back(PicoLed::RGB(255, 0, 255));
            PicoLed::Marquee effect_marquee(aime_led, rainbow_palette, 3.0, -2.0, 1.0);

            tusb_init();
            while (true) {
                tud_task();

                uint8_t this_mode = get_mode();
                switch (this_mode) {
                case MODE::KEYBOARD:
                    if (last_mode != this_mode) {
                        aime_led.setBrightness(0x2f);
                        led_board::set_color(0xff, 0xff, 0xff);
                        led_board2::set_color(0xff, 0xff, 0xff);
                        using namespace component::mai2_hardware;
                        set_led(0xffffff);
                        set_led_brightness(0x4f);
                    }
                    if (effect_marquee.animate())
                        aime_led.show();

                    component::mai2_hardware::update_keyboard(&output_keyboard_data);

                    if (tud_hid_ready())
                        tud_hid_report(0x02, &output_keyboard_data, sizeof(output_keyboard_data));
                    break;
                case MODE::IO4:
                    if (last_mode != this_mode){
                        aime_led.setBrightness(0xff);
                        aime_reader::set_card_light(0, 0, 0);
                        led_board::init_color();
                        led_board2::init_color();
                        using namespace component::mai2_hardware;
                        set_led(0xffffff);
                        set_led_brightness(0xff);
                    }

                    component::mai2_hardware::update_hardware(&output_data);

                    if (tud_hid_ready())
                        tud_hid_report(0x01, &output_data, sizeof(output_data));
                    break;
                default:
                    break;
                }
                last_mode = this_mode;
                vTaskDelay(6 / portTICK_PERIOD_MS);
            }
        }

        void process_data(const input_t *data) {
            switch (data->cmd) {
                case io4_usb::SET_COMM_TIMEOUT:
                    //uart_puts(uart1,"IO4: Set Communicate Timeout\n");
                    output_data.system_status = 0x30;
                    break;
                case io4_usb::SET_SAMPLING_COUNT:
                    //uart_puts(uart1,"IO4: Set Sampling Count\n");
                    output_data.system_status = 0x30;
                    break;
                case io4_usb::CLEAR_BOARD_STATUS:
                    // uart_puts(uart1,"IO4: Clear Board Status\n");
                    output_data.coin[0].count = 0;
                    output_data.coin[0].condition = io4_usb::coin_condition_t::normal;
                    output_data.coin[1].count = 0;
                    output_data.coin[1].condition = io4_usb::coin_condition_t::normal;
                    output_data.system_status = 0x00;
                    break;
                case io4_usb::SET_GENERAL_OUTPUT: {
                    uint32_t ledData = data->payload[0] << 16 | data->payload[1] << 8 | data->payload[2];
                    component::mai2_hardware::set_led(ledData);
                    //uart_puts(uart1,"IO4: Set General Output\n");
                    break;
                }
                default:
                    break;
            }
        }

//--------------------------------------------------------------------+
// USB HID
//--------------------------------------------------------------------+

// Invoked when received GET_REPORT control request
// Application must fill buffer report's content and return its length.
// Return zero will cause the stack to STALL request
        extern "C" uint16_t
        tud_hid_get_report_cb(uint8_t itf, uint8_t report_id, hid_report_type_t report_type, uint8_t *buffer,
                              uint16_t reqlen) {
            return 0;
        }

// Invoked when received SET_REPORT control request or
// received data on OUT endpoint ( Report ID = 0, Type = 0 )
        extern "C" void
        tud_hid_set_report_cb(uint8_t itf, uint8_t report_id, hid_report_type_t report_type, uint8_t const *buffer,
                              uint16_t buf_size) {
            auto data = reinterpret_cast<const component::io4_usb::input_t *>(buffer);
            if (data->report_id== 0x10) {
                process_data(data);
            }
        }
    }
}

whowechina, 2024-02-13:
谢谢！
不过不需要大块贴代码，这样会把讨论弄很乱，一般一两行就足够表达意思了。
我回头空了自己摸索一下，应该非常简单。
另外我倾向于简洁的公开讨论，如果能用英文更好。

CY202032, 2024-02-13:
I'm really sorry, my English is very poor, so I can't read some sentences. Sorry again, thank you for your efforts. I like this project very much, and it's very stable so far.

whowechina, 2024-02-14:
> I'm really sorry, my English is very poor, so I can't read some sentences. Sorry again, thank you for your efforts. I like this project very much, and it's very stable so far.

哈，没事。只是这个仓库面对很多不同语言的人，英语会方便别人而已，说不定别人还能帮忙。

CY202032, 2024-02-15:
[Mai2LED.zip](https://github.com/whowechina/mai_pico/files/14296536/Mai2LED.zip)

This is the project file, which contains the light self-inspection part of 837-15070-04. I hope you can learn from it. It's a pity that I haven't had time to test the project you updated.

这是工程文件，里面包含了837-15070-04的灯光自检部分，希望能借鉴，您更新的工程我还没有时间测试，真是可惜呢。。

CY202032, 2024-02-16:
After testing, it was found that the updated project lighting had serious issues, and the buttons did not respond. They began to input strings on their own. Unable to further test...

经过测试，更新的项目灯光出现了严重的问题，按键也无反应了，开始自行输入字符串。无法进一步测试。。。

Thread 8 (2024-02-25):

IO板与ITO玻璃解耦合，接插件的选择，layout优化

imfrea, 2024-02-25:
#### 一、接插件的选择
个人认为针对本项目的实际情况，按钮的走线设计和体积，保留JST EH连接器没有太多意义，在此建议如下：
1. 在IO板上多增加一个集中式的8PIN SH1.25端子座，定义为BT1…BT8
以及相应的SH1.25 3P（RGB输出）
按钮板则可以统一焊接一根SH1.25单头端子线（如图）
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

2. 在按钮PCB的J2/J4任意一个焊盘与GND之间预留一个0R电阻位，短接时共地，可节约简化走线（如图）
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

#### 二、IO板与ITO玻璃解耦合
目前控制板与ITO玻璃一对一焊死，不利于后期搬运和维护
出于DIY条件有限的考虑，无法直接将普通FPC绑定到ITO玻璃上
1. 建议增加一片0.8mm厚的PCB将1.6mm斑马纸排线转为常见的1.0间距34P的FPC排线（双头或单头焊接），并布置相应的排线座

其他方案：或许可以将3颗MPR121分立器件单独置于一块PCB上，缩短触屏线路的距离，另一端则使用I2C连接到IO板（如果I2C不适合长距离传输，请您考虑增加一颗MCU将信号流处理并转换为串口通讯）

#### 三、layout优化
原型PCB的layout不是十分紧凑
1.建议新的PCB中取消MPR121模块的设计，仅保留MPR121分立设计（分立电路部分经过验证可用），且芯片的价格低于模块

2.其他：考虑采用RP2040 Zero模块？因为体积小巧io也足够（模块反面有元件，可在PCB中间开窗，沉板设计，模块的Type-C接口直接对外（大致示意如图）
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

双面元器件以及4层设计？

希望您能考虑采用立创EDA绘制PCB，有助于节约打样成本
*****
以上均为个人的想法和意见，可能不是很成熟，恳请您认真考虑和是否要采纳。

抱歉，我的英语不好，我也不会使用PCB设计软件，请见谅。
我正计划“本土化”文档并补充更多的细节与提示。
如果可能，希望您能在关闭issue前，留下**Email**以便交流，谢谢！

whowechina, 2024-02-25:
谢谢提想法。虽然项目里有很多值得改进的细节，但我暂时不打算更新 PCB。
它现在对爱好者来说“可用”、“够用”，个人 DIY，过程就是乐趣，不会太介意多焊接几个点；作为”商品“也许有很多不足，但因为我极力反对任何人用本项目来”盈利“，所以没计划做这些改进。

中文的指南我后续会在本仓库更新，方便国内爱好者。

whowechina, 2024-02-25:
中文版本指南发布后我会关闭这个 Issue。
任何制作过程中发现的问题可以在这里开 Issue 咨询，但务必不要提及任何游戏拷贝相关的内容。

Closed 2024-02-25.

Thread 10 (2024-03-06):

About the self-test interaction of the light control panel

CY202032, 2024-03-06:
Hope to repair this function, 15070-04, although it can be used at present, but always feel uncomfortable, obsessive-compulsive disorder patients said very uncomfortable. Ha ha ha

CY202032, 2024-03-07:
Sorry, I don't know what the details are, just I don't understand, I tried to port the code, but it failed.

#if defined(__AVR_ATmega32U4__) || defined(ARDUINO_SAMD_ZERO)
#pragma message "当前的开发板是 ATmega32U4 或 SAMD_ZERO"
#define SerialDevice SerialUSB
#define LED_PIN 5

#elif defined(ESP8266)
#pragma message "当前的开发板是 ESP8266"
#define SerialDevice Serial
#define LED_PIN D1

#elif defined(ESP32)
#pragma message "当前的开发板是 ESP32"
#define SerialDevice Serial
#define LED_PIN 13

#else
#error "未经测试的开发板，请检查串口和针脚定义"
#endif

#define NUM_LEDS 11
#include "FastLED.h"
CRGBArray<NUM_LEDS> leds;

enum {
  Sync = 224,
  Marker = 208,

  ResetCommand = 16,
  SetTimeout = 17,
  SetLedGs8Bit = 49,
  SetLedGs8BitMulti = 50,
  SetLedGs8BitMultiFade = 51,
  SetLedFet = 57,
  SetDcUpdate = 59,
  SetLedGsUpdate = 60,
  SetDc = 63,
  SetEEPRom = 123,
  GetEEPRom = 124,
  SetEnableResponse = 125,
  SetDisableResponse = 126,
  SetLedDirect = 130,
  GetBoardInfo = 240,
  GetBoardStatus = 241,
  GetFirmSum = 242,
  GetProtocolVersion = 243,
  SetBootMode = 253,

  AckStatus_Ok = 1,
  AckStatus_SumError = 2,
  AckStatus_ParityError = 3,
  AckStatus_FramingError = 4,
  AckStatus_OverRunError = 5,
  AckStatus_RecvBfOverFlow = 6,
  AckStatus_Invalid = 255,

  AckReport_Ok = 1,
  AckReport_Busy = 2,
  AckReport_CommandUnknown = 3,
  AckReport_ParamError = 4,
  AckReport_Invalid = 255
};

typedef union {
  uint8_t buffer[39];
  struct {
    struct {
      // uint8_t sync;
      uint8_t dstNodeID;
      uint8_t srcNodeID;
      uint8_t length;
      uint8_t command;
    };
    union {
      uint8_t timeout;  // SetTimeout
      struct {          // SetLedGs8Bit
        uint8_t index;
        uint8_t color[3];
      };

      struct {  // SetLedGs8BitMulti, SetLedGs8BitMultiFade, SetDc
        uint8_t start;
        uint8_t end;  //length
        uint8_t skip;
        uint8_t Multi_color[3];
        uint8_t speed;
      };
      struct {  // SetLedFet
        uint8_t BodyLed;
        uint8_t ExtLed;
        uint8_t SideLed;
      };
      struct {  // SetEEPRom
        uint8_t Set_adress;
        uint8_t writeData;
      };
      uint8_t Get_adress;           // GetEEPRom
      uint8_t Direct_color[11][3];  // SetLedDirect
    };
    // uint8_t sum;
  };
} PacketReq;

typedef union {
  uint8_t buffer[12];
  struct {
    struct {
      // uint8_t sync;
      uint8_t dstNodeID;
      uint8_t srcNodeID;
      uint8_t length;
      uint8_t status;
      uint8_t command;
      uint8_t report;
    };
    union {
      uint8_t eepData;  // GetEEPRom
      struct {          // GetBoardInfo
        uint8_t boardNo[9];
        uint8_t firmRevision;
      };
      struct {  // GetBoardStatus
        uint8_t timeoutStat;
        uint8_t timeoutSec;
        uint8_t pwmIo;
        uint8_t fetTimeout;
      };
      struct {  // GetFirmSumCommand
        uint8_t sum_upper;
        uint8_t sum_lower;
      };
      struct {  // GetProtocolVersionCommand
        uint8_t appliMode;
        uint8_t major;
        uint8_t minor;
      };
    };
    // uint8_t sum;
  };
} PacketAck;

static PacketReq req;
static PacketAck ack;

static uint8_t packet_read() {
  static uint8_t r_len, r, checksum;
  static bool escape = false;
  while (SerialDevice.available()) {
    r = SerialDevice.read();
    if (r == Sync) {
      r_len = 0;
      checksum = 0;
      continue;
    }
    if (r == Marker) {
      escape = true;
      continue;
    }
    if (escape) {
      r++;
      escape = false;
    }

    if (r_len == req.length + 3) {
      if (checksum == r) {
        return req.command;
      }
      return AckStatus_SumError;
    }
    req.buffer[r_len++] = r;
    checksum += r;
  }
  return 0;
}

void packet_write() {
  if (ack.command == 0) {
    return;
  }
  uint8_t checksum = 0, w_len = 0;
  SerialDevice.write(Sync);
  while (w_len < ack.length + 3) {
    uint8_t w;
    w = ack.buffer[w_len++];
    checksum += w;
    if (w == Sync || w == Marker) {
      SerialDevice.write(Marker);
      SerialDevice.write(--w);
    } else {
      SerialDevice.write(w);
    }
  }
  SerialDevice.write(checksum);
  ack.command = 0;
}

static uint8_t dummyEEPRom[8] = { 0, 0, 0, 0, 0, 0, 0, 0 };

void ack_init(uint8_t length = 0, uint8_t status = AckStatus_Ok, uint8_t report = AckReport_Ok) {
  ack.dstNodeID = req.srcNodeID;
  ack.srcNodeID = req.dstNodeID;
  ack.length = 3 + length;
  ack.status = status;
  ack.command = req.command;
  ack.report = report;
}

void setLedGs8Bit() {
  leds[req.index] = CRGB(req.color[0], req.color[1], req.color[2]);
  ack_init();
}

long StartFadeTime, EndFadeTime, progress;
uint8_t StartFadeLed, EndFadeLed;
CRGB StartFadeColor, EndFadeColor;
bool NeedFade = false;

void setLedGs8BitMulti() {
  if (req.end == 32) {  // SetLedDataAllOff
    req.end = NUM_LEDS;
  }
  StartFadeColor = CRGB(req.Multi_color[0], req.Multi_color[1], req.Multi_color[2]);
  leds(req.start, req.end - 1) = StartFadeColor;
  NeedFade = false;
  ack_init();
}

void setLedGs8BitMultiFade() {
  EndFadeColor = CRGB(req.Multi_color[0], req.Multi_color[1], req.Multi_color[2]);
  StartFadeTime = millis();
  EndFadeTime = StartFadeTime + (4095 / req.speed * 8);
  StartFadeLed = req.start;
  EndFadeLed = req.end - 1;
  NeedFade = true;
  ack_init();
}

void setLedFet() {  // 框体灯，只有白色，值代表亮度，会多次发送实现渐变，需要立刻刷新
#if NUM_LEDS > 8
  leds[8] = blend(0x000000, 0xFFFFFF, req.BodyLed);
  leds[9] = blend(0x000000, 0xFFFFFF, req.ExtLed);    //same as BodyLed
  leds[10] = blend(0x000000, 0xFFFFFF, req.SideLed);  //00 or FF
  FastLED.show();
#endif
  ack_init();
}

void getBoardInfo() {
  memcpy(ack.boardNo, "15070-04\xFF", 9);
  ack.firmRevision = 144;
  ack_init(10);
}

void getBoardStatus() {  // unknown
  ack.timeoutStat = 0;
  ack.timeoutSec = 0;
  ack.pwmIo = 0;
  ack.fetTimeout = 0;
  ack_init(4);
}

void getFirmSum() {  // unknown
  ack.sum_upper = 0;
  ack.sum_lower = 0;
  ack_init(2);
}

void getProtocolVersion() {  // unknown
  ack.appliMode = 1;         // IsNeedFirmUpdate = false
  ack.major = 0;
  ack.minor = 0;
  ack_init(3);
}

void setup() {
  FastLED.addLeds<WS2812B, LED_PIN, GRB>(leds, NUM_LEDS);
  // FastLED.setBrightness(30);
  FastLED.clear();
  SerialDevice.begin(115200);
  FastLED.showColor(0xFFFFFF);
  memset(req.buffer, 0, sizeof(req.buffer));
  memset(ack.buffer, 0, sizeof(ack.buffer));
}

void loop() {
  switch (packet_read()) {
    case AckStatus_SumError:
      ack_init(0, AckStatus_SumError, 0);
      break;
    case SetLedGs8Bit:
      setLedGs8Bit();
      break;
    case SetLedGs8BitMulti:
      setLedGs8BitMulti();
      break;
    case SetLedGs8BitMultiFade:
      setLedGs8BitMultiFade();
      break;
    case SetLedFet:
      setLedFet();
      break;
    case SetLedGsUpdate:
      FastLED.show();
      ack_init();
      break;
    case SetEEPRom:
      dummyEEPRom[req.Set_adress] = req.writeData;
      ack_init();
      break;
    case GetEEPRom:
      ack.eepData = dummyEEPRom[req.Get_adress];
      ack_init(1);
      break;
    case GetBoardInfo:
      getBoardInfo();
      break;
    case GetBoardStatus:
      getBoardStatus();
      break;
    case GetFirmSum:
      getFirmSum();
      break;
    case GetProtocolVersion:
      getProtocolVersion();
      break;
    case SetEnableResponse:
    case SetDisableResponse:
    case 0:
      break;
    default:
      ack_init();
  }
  packet_write();

  if (!NeedFade) return;
  if (millis() > EndFadeTime) {
    progress = 255;
    NeedFade = false;
  } else {
    progress = map(millis(), StartFadeTime, EndFadeTime, 0, 255);
  }
  leds(StartFadeLed, EndFadeLed) = blend(StartFadeColor, EndFadeColor, progress);
  FastLED.show();
}

whowechina, 2024-03-08:
What is "Light Control Panel" and what is "self-test interaction"?
I don't need codes, I just don't understand the problem.

CY202032, 2024-03-08:
The problem is that when the status of the device is reported when the game starts, the led says bad, not good.

whowechina, 2024-03-08:
Ah ok, I'll check that.

whowechina, 2024-03-08:
I can't reproduce it. I tested with Festival JP version, the first 4 lines (Touch and LED for 1P/2P) all GOOD.

CY202032, 2024-03-08:
No, no, no.You can put the mai2.ini Turn off the test for DummyLED.Let this item be 0, not 1.

[AM]
DummyLED=0

CY202032, 2024-03-09:
LED handler: Comio.BD15070_4.BoardCtrl15070_4._execThread()
Print LED control data: Comio.Packet.dump()
Serial packet codec Comio.JvsSyncProtect
With DummyLED enabled, Comio.BoardCtrlBase.SendForceCommand still sends light data

The attachment is the data of the packet capture, which is for reference only, I hope it will help the logic

Thank you for your contribution to this project

[MaiLED-Data.txt](https://github.com/whowechina/mai_pico/files/14544316/MaiLED-Data.txt)

whowechina, 2024-03-09:
> No, no, no.You can put the mai2.ini Turn off the test for DummyLED.Let this item be 0, not 1.
>
> [AM] DummyLED=0

Got it.

Closed 2024-03-09.

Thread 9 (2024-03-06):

ITO Glass question

shorax, 2024-03-06:
Thanks for this guide, but i have a question, what should the size of ITO glass be?
 length x width, so i know what o request as i couldnt find the radius of the print...

imfrea, 2024-03-06:
250mm*250mm

CY202032, 2024-03-06:
250*250*2mm，I hope I can help you.

Closed 2024-03-06.

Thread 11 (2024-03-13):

ITO glass and full size maimai questions

OliverLSanz, 2024-03-13:
Hello Wowechina. First of all thank you for this and your other projects, all look amazing!

I have never used ITO glass. I have a question about it. If you touch the narrow strips that connect each touch area to the sensors, won't it make the sensor trigger? For example, if I touch here, won't the "X" marked areas trigger? Why?
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

Also, I'm thinking about modifying the design to build a full size controller. Can you anticipate any major drawbacks or difficulties from doing this? (apart from cost of the materials, of course)

whowechina, 2024-03-14:
It's all about SNR (signal to noise ratio), in this case, signal is the capacity change when a finger approaches to the electrode (so the area of the electrode matters, in a linear way). Traces is like nothing compared with main touch area.

Firmware and design work for fullsize. In fact, SNR on fullsize should be better.
Making a full size ITO is just not worth, way too expensive, even if you make a 5 pcs batch.

OliverLSanz, 2024-03-14:
I understand, thank you!

Could a IR Touch Frame replace the ITO Glass? I'm pondering the pros and cons and maybe you have any insight that will make me see that an IR Touch Frame is not a good idea.

whowechina, 2024-03-14:
Then you have to change the code by youself.

OliverLSanz, 2024-03-14:
I know about the code, just wondering if yoy had any insights to share about IR Frame. Thank you again 😄

Closed 2024-03-14.

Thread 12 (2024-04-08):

更新后固件刷上触摸只识别A1区

5huxiaoyang6, 2024-04-08:

whowechina, 2024-04-08:
Execute ‘factory’ command to reset to factory default settings. This is because a new touch mapping introduced in new firmware. Sorry about the inconvenience.在 2024年4月8日，11:58，5huxiaoyang6 ***@***.***> 写道：

—Reply to this email directly, view it on GitHub, or unsubscribe.You are receiving this because you are subscribed to this thread.Message ID: ***@***.***>

whowechina, 2024-04-13:
Made some change. When upgrading from an old version which makes the touch map corrupted, it automatically resets the touch map to default.

Closed 2024-04-13.

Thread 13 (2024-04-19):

Questions about the new AIC module in this project..

CY202032, 2024-04-19:
The new module is available, but at the beginning of the game, the network will be disconnected when repeatedly swiping the AIME card. I changed to other card readers and no similar problems occurred. After entering the test mode, I found that AIME did It works fine, but I don't know what went wrong.

新的模块是可用的，但是在游戏开始时，反复刷AIME卡的时候会出现断网的情况，我换了其他的读卡器，并没哟出现类似问题，进入test模式后发现AIME并没有掉，功能还是正常的，不清楚到底哪里出了问题。

whowechina, 2024-04-21:
No idea why this happens. Have you tried with a standalone AIC Pico?
I noticed a short-lived "aime not available at this time" message before, and didn't figure out why. As it's not a big problem, I didn't dig into it.

whowechina, 2024-04-22:
I think I've found a fix for the issue, will update shortly.

whowechina, 2024-04-30:
Fixed.

Closed 2024-04-30.

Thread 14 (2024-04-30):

A new bug in the AIC module

CY202032, 2024-04-30:
When swiping the card, you can press the 7 key to view the card number. When you quickly slide the AIME card or compatible card over the card reader, you will get the card number 0000-0000-0000-0000-0000 instead of your card number.

在刷卡的时候你可以按7键查看卡号，当你快速的将AIME卡或兼容卡从读卡器上滑过，你会得到的卡号0000-0000-0000-0000-0000而不是你的卡号。

whowechina, 2024-04-30:
What if you swipe slowly? Process of reading aime card is slow.

CY202032, 2024-04-30:
If I swipe slowly, it will be the correct card number, which is a small issue. Leaving it aside for now, there is another issue with the RGB standby light. If you are checking the card number and the idle light is on, or at other times, the idle light is on, it looks great. Then you return to the main page to swipe the card, but you don't clear the light effect and then turn on the corresponding light. Instead, you directly turn on the corresponding light.

whowechina, 2024-05-04:
You mean the idle light effect is intruding the gaming light?

whowechina, 2024-05-06:
Nothing I can do to accelerate the card reading.

Closed 2024-05-06.

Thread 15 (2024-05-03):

修复灯光问题。。。。

CY202032, 2024-05-03:
老哥灯光需要修复的一些问题。。。数据进行对比更接近官方15070-04的数据...基本一致。

```c
static void ack_ok(cdc_t *cdc)
{
    led_resp_t *resp = led_init_resp(cdc, 0);
    led_write(cdc, resp);
}
void setDc(cdc_t *cdc) {
    ack_ok(cdc);
}
static void getBoardInfo(cdc_t *cdc)
{
    led_resp_t *resp = led_init_resp(cdc, 12);
    memcpy(resp->payload, "15070-04\xff\x90\x00\x30", 12);
    led_write(cdc, resp);
}
void setDcUpdate(cdc_t *cdc) {
    ack_ok(cdc);
}

void setLedGsUpdate(cdc_t *cdc) {
    ack_ok(cdc);
}

void setLedGs8Bit() {
    uint32_t color = rgb32(cdc->led.color[0], cdc->led.color[1], cdc->led.color[2], false);
    setLedColor(color, cdc->led.index, 1, 0);
    ack_ok(cdc);
}

void setLedGs8BitMulti() {
    uint32_t color = rgb32(cdc->led.Multi_color[0], cdc->led.Multi_color[1], cdc->led.Multi_color[2], false);
    setLedColor(color, cdc->led.start, cdc->led.len, 0);
    ack_ok(cdc);
}

void setLedGs8BitMultiFade() {
    uint32_t color = rgb32(cdc->led.Multi_color[0], cdc->led.Multi_color[1], cdc->led.Multi_color[2], false);
    setLedColor(color, cdc->led.start, cdc->led.len, cdc->led.speed);
    ack_ok(cdc);
}

void setLedFet() {
    rgb_set_cab(0, gray32(cdc->led.BodyLed, false));
    rgb_set_cab(1, gray32(cdc->led.ExtLed, false));
    rgb_set_cab(2, gray32(cdc->led.SideLed, false)); // 设置框体灯
    ack_ok(cdc);
}

static void led_cmd(cdc_t *cdc)
{
 case ResetCommand: //0x10
            ack_ok(cdc);
 break;
case SetDcUpdate ://0x3B
            setDcUpdate(cdc);
            //printf("SetDcUpdate  \n");
            break;
        case SetLedGsUpdate://0x3C
            setLedGsUpdate(cdc);
            //printf("SetLedGsUpdate \n");
            break;
        case SetDc://0x3F
            //printf("SetDc \n");
            setDc(cdc);
            break;
        case SetEEPRom:
            set_eeprom(cdc);
            break;
        case GetEEPRom:
            get_eeprom(cdc);
            break;
        case GetBoardInfo://0xF0
            //printf("GetBoardInfo \n");
            getBoardInfo(cdc);
            break;
        case GetBoardStatus://0xF1
            //printf("GetBoardStatus \n");
            getBoardStatus(cdc);
            break;
        case GetFirmSum://0xF2
            //printf("GetFirmSum \n");
            getFirmSum(cdc);
            break;
        case GetProtocolVersion ://0xF3
            //printf("GetProtocolVersion \n");
            getProtocolVersion(cdc);
            break;
        case SetLedDirect://0x82
            ack_ok(cdc);
            //printf("SetLedDirect \n");
            break;
        default:
            ack_ok(cdc);
            return;
    }
}
```

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

这个单元我重新写了一些结构，我就不一一写了，希望老哥这个项目更完整

whowechina, 2024-05-03:
只说具体问题和现象，别贴代码。

CY202032, 2024-05-04:
目前的问题是版号会显示方块，而不是15070-04，在询问的时候会乱回复数据，数据格式不对等等问题，比如010203040506本来应该回复111213141516，抓包发现它回复的数据比较乱，可能会回复1112131415161718，111213141516171811121315171819之类的，之前没注意，不过已经搞定了

whowechina, 2024-05-04:
So it's not functional thing. The firmware is not giving proper info strings to the game. Thanks. I'll fix them some time later.

CY202032, 2024-05-04:
对了，还有一个关于hid的功能。。。
```c#
void hid_proc(const uint8_t *data, uint8_t len)
{
    hid_output_t *output = (hid_output_t *)data;
    if (output->report_id == REPORT_ID_OUTPUT) {
        switch (output->cmd) {
            case 0x01: // Set Timeout
            case 0x02: // Set Sampling Count
                hid_joy.system_status = 0x30;
                break;
            case 0x03: // Clear Board Status
                hid_joy.chutes[0] = 0;
                hid_joy.chutes[1] = 0;
                hid_joy.system_status = 0x00;
                break;
            case 0x04: // Set General Output
            case 0x41: // I don't know what this is
                break;
            default:
                printf("USB unknown cmd: %d\n", output->cmd);
                break;
        }
    }
```

0x41是广告牌的灯光检查，好像是顶灯，具体我没细研究，好像用处不大，数据得到了几个，有兴趣您可以研究研究。
10 41 FC 00 FF 00 00 00 00 00 红色
10 41 FC 00 00 00 FF 00 00 00 绿色
10 41 FC 00 00 00 00 00 FF 00 蓝色
10 41 FC 00 FF 00 FF 00 FF  00 白色

10 41 FC 00 FF FF 73 73 00 00 1.40的颜色，这个RGB色盘应该是rgb(255, 115, 0)
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

whowechina, 2024-05-09:
> 目前的问题是版号会显示方块，而不是15070-04，在询问的时候会乱回复数据，数据格式不对等等问题，比如010203040506本来应该回复111213141516，抓包发现它回复的数据比较乱，可能会回复1112131415161718，111213141516171811121315171819之类的，之前没注意，不过已经搞定了

I can't reproduce the issue with my limited data resource. I'll close this one for now.
In the future, please only describe the issue, how to reproduce it, or the errors in the code.

whowechina, 2024-05-09:
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
Yeah, I'll add cab light support in the future. Thanks.

Closed 2024-05-09.

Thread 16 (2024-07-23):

Bro, can you separate the touch part and use DB9, RS232 for direct communication?

CY202032, 2024-07-23:
I just want to use the native protocol to connect directly to the COM interface.

whowechina, 2024-07-23:
No idea what it means.
Mai Pico uses native protocol to talk to the arcade game thru a COM port.

CY202032, 2024-07-23:
Actually, it's nothing, I just remembered it suddenly, promicro, esp32 and other development boards have this version, I suddenly remembered that 2040 doesn't have it, so I asked

whowechina, 2024-07-23:
rp2040 has UARTs, but at 3.3V level, not RS232 level.
For maimai, there's no difference between USB CDC COM port and an ISA-RS232 COM port.

CY202032, 2024-07-23:
OK,Close.

Closed 2024-07-23.

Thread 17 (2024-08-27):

关于外壳

IlIIllllIlIIlll, 2024-08-27:
你好！我画好了一个外壳，我该如何贡献这个项目，我是新手，不太会用github
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

whowechina, 2024-08-27:
感谢。
如果你自己有 github 账号和仓库，可以在自己的 github 页面发布（记得要同时发布源文件，可供他人二次编辑和加工的，并建议使用任何非商用类的协议，比如像我这样的 CC-NC），然后给我几张你成品的照片，我放到我的介绍里，并链接到你的仓库页面。

如果你不打算自行发布 github 仓库，把文件发给我，我可以放到我这边页面里面，我会写上原作者。

IlIIllllIlIIlll, 2024-08-27:
想问一下，我如何怎么把文件发给你？是以邮箱的方式发送吗？

whowechina, 2024-08-27:
可以试试在这里直接加附件。

IlIIllllIlIIlll, 2024-08-27:
我在这里没法上传大文件

whowechina, 2024-08-27:
最好你自己开个仓库分享外壳制作过程，包括选材，工艺，确保都是大家能容易订购到的。
我会把你的作品和仓库链接加到 Builds Gallery （制作集锦）里面。 你可以看看现在已经有几位爱好者的作品和链接了，其中 imfrea 也做了一个外壳。

IlIIllllIlIIlll, 2024-08-27:
[mai pico外壳.zip](https://github.com/user-attachments/files/16762639/mai.pico.zip)

whowechina, 2024-08-27:
看上去 STL 的都是需要打印的，正面背面材料应该是亚克力吧，多厚的？

whowechina, 2024-08-27:
另外你给几个好看点的成品照片，以及你希望留下的你的名字（网民，昵称都可以）。

IlIIllllIlIIlll, 2024-08-27:
> 看上去 STL 的都是需要打印的，正面背面材料应该是亚克力吧，多厚的？

正面和背面的材料是pp板材，边框可以亚克力定制也可以3D打印，支柱是3D打印，稍后晚点我写个装配过程文档。

IlIIllllIlIIlll, 2024-08-27:
> 另外你给几个好看点的成品照片，以及你希望留下的你的名字（网名，昵称都可以）。

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

IlIIllllIlIIlll, 2024-08-27:
昵称就我现在github名

whowechina, 2024-08-29:
> > 看上去 STL 的都是需要打印的，正面背面材料应该是亚克力吧，多厚的？
>
> 正面和背面的材料是pp板材，边框可以亚克力定制也可以3D打印，支柱是3D打印，稍后晚点我写个装配过程文档。

主要是材料选择（购买的时候需要提供的文件，参数等等），还包括螺丝的参数等等，大家可以根据你提供的参数自行找到供应商。

等你给我后，我更新上去。

whowechina, 2024-09-03:
[7cb63b9](https://github.com/whowechina/mai_pico/commit/7cb63b93b9c24e5c1854f27253f25c45fcd50ca1)

Closed 2024-09-03.

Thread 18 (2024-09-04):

Question about Pop'n Pico - Screws/Spacers

AbsentmindedGCN, 2024-09-04:
Hi there, sorry this issue is being uploaded in the wrong spot.
Could you please provide more information about the screws/spacer solution for the Pop'n Pico?
https://github.com/whowechina/popn_pico

I cannot find any 3.4mm/3.5mm M3 spacers. Do you have any suppliers that create them and the M3 screws?
Any help/advice would be extremely appreciated. Thanks a bunch!

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

whowechina, 2024-09-04:
Google "hexagonal brass standoff". You may get a 4mm one and use a grinder to trim to 3.4mm.
Popn Pico is my first attempt in my Pico Series, by the time I was not so experience, the housing design choices was not the best.

AbsentmindedGCN, 2024-09-05:
Thank you very much! This is my first project I've tried to 3D print and I'm really excited.
I have another question if you have a moment. When trying to print these with JLC, they are saying that the bottom wall thickness is too thin, causing high risks of cracks and deformation. They recommend increasing the size to at least 0.8mm, but 1.5mm would be ideal.

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

Would it be possible to increase these to 0.8mm and update the STL? I am very sorry to ask but I do not have access to AutoCAD.

whowechina, 2024-09-05:
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

Those places are supposed to be that thin. I printed on my old cheap printer, and it went well. So as long as the print bed is properly leveled it will be fine.
3D printing is not durable as commercial products, it's more for prototyping or for hobby projects like this.

AbsentmindedGCN, 2024-09-05:
This is a hobby project, I am excited to play Pop'n. :)
I will go ahead with the 3D print if you think there is no issue with it being 0.6mm. I do not have a 3D printer so I am ordering the 3D printed parts from JLC.
Thank you very much for creating this!

AbsentmindedGCN, 2024-09-05:
Do you have the original source file for the STL that I can edit? I would like to increase the size of the bottom by 1mm if possible. I tried to make an adjustment but editing the STL file is difficult and it will not work for JLC to print. :(
[pico_popn_case_updated.zip](https://github.com/user-attachments/files/16885066/pico_popn_case_updated.zip)

Closed 2024-09-04.

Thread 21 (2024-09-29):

Pop'n Pico - No Response/USB Issue

AbsentmindedGCN, 2024-09-29:
Hi whowechina!

I am sorry for bothering you again but I had another question regarding the Pop'n Pico. I was able to get the parts, PCBs, and printed case. I have been trying to solder everything, but I have been running into an issue.

When I plug the board into my computer, either by USB-C or Micro-USB, the board won't respond. Any other USB devices will stop working, like my USB mouse, or my external HDD. I have tried holding the BOOTSEL button down and that makes no difference. I have tried soldering one board then putting the firmware on, and another board where I put the firmware on before soldering. The issue occurs on both boards, across multiple PCs.

I am trying to determine the source of the issue but I'm honestly very lost and not sure what the issue is. Photos of the 2 boards I soldered are below:

Board 1: (This was messy with flux, sorry!!)
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

Board 2 (no RGB):
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

I have a couple of questions if you have a moment:
Do you see any noticeable problems on the board that could be causing this issue?
Are there any pins on the Pico I'm not supposed to solder?
What is the most likely part/section that could be causing this? (eg. resistors?)

Any help/advice would be really appreciated. I'm sorry again for being bothersome.
Thank you again for making this project and sharing it with others, it has been really fun to learn SMD soldering!

whowechina, 2024-09-29:
You may move the issue to Pop'n repo (I just enabled it there).
USB not responding is because there's some short-circuit, very likely at the Type-C connector soldering.
And 4020 LEDs on your first board are facing wrong direction.

whowechina, 2024-09-29:
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
This looks not good.

whowechina, 2024-09-29:
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
This also not good.

The 4 bigger pins at both sides are VCC and GND, if they touch each other, boom!

AbsentmindedGCN, 2024-09-29:
Thank you so so much for checking. I will resolder the USB-C. I will also move this over to the Pop'n Pico project if I have any other issues. I'm very sorry for bothering and really appreciate your help.

Will this USB-C still cause an issue even when connecting with microUSB? I was surprised the issue was still happening even without USB-C.

Thank you again for your help!!

AbsentmindedGCN, 2024-09-29:
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
Is this any better or is the USB-C still an issue

This is not responding when connected to my PC :(

whowechina, 2024-09-30:
> ![20240929_184956](https://private-user-images.githubusercontent.com/170419498/371907383-e9763a47-682d-41da-a86e-b611c11fa1d7.jpg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) Is this any better or is the USB-C still an issue
>
> This is not responding when connected to my PC :(

This looks better. This time it didn't stop other devices right?

Very likely these three are not soldered to the pad (air bubbles in them).
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

whowechina, 2024-09-30:
By the way, using a cotton swab dipped in PCB cleaner can nicely clean the PCB board.

AbsentmindedGCN, 2024-09-30:
It's still stopping other devices and not working. :(
I will clean the PCB

Do you have any tips on soldering the 3 holes? I put the iron into the solder to get it to the bottom of the pico after soldering it to the other side of the board

Would the resistors be a problem that could cause this? I'm trying to think why the same issue would happen with USB-C and Micro USB

whowechina, 2024-09-30:
In some other repos (maybe chu_pico or geki_pico), I left some notice for these pins.
Resistors won't cause this problem. Wrong orientation of LEDs or short-circuit of VCC and GND could lead to this problem.

AbsentmindedGCN, 2024-09-30:
I checked the orientation of the LEDs (they lit up while soldering) and made sure those were on the right side. The RGB lights were difficult and I am not sure if I am able to include them. Are they necessary for the board to work?

I will check for any short circuits on the Pico

AbsentmindedGCN, 2024-10-01:
Thank you for your help!! I cleaned up the boards and jammed my soldering iron through the 3 holes to make sure they got soldered through. That fixed one of the boards!

I'm not getting any LEDs working, and I'm going to try to fix/make another board, but I'm really excited this one works!!

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

Thank you again for making this project and thank you for all your help! This has been really fun to do!!
Do you accept donations anywhere?

whowechina, 2024-10-01:
Only RGB LED could lead to short-circuit if orientation is wrong.
Congratulations on your first DIY con, there're other pico cons I made. :)
The firmware allows light brightness and fading controll.

No, I don't accept donations.
Just encourage more of your friends to build my pico series cons.

Closed 2024-10-01.

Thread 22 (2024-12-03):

button and touchscreen cannot work together in my mai pico. What could be the possible solution

Panda2397, 2024-12-03:
The 8 main button only have button 4 5 6 are workable with touchscreen worked. However, when I replug the USB, all 8 button can simulate keyboard output (it worked) but touchscreen didn't work.

whowechina, 2024-12-04:
Sounds like it's not a mai pico hardware or firmware issue.
You can try IO4 mode.

Panda2397, 2024-12-04:
Thanks for your answer. I have changed the LED from com21 to others and
finally the button worked. However the LED dont. What could be the possible
reason for that

在 2024年12月4日週三 下午3:11，whowechina ***@***.***> 寫道：

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

Closed 2024-12-04.

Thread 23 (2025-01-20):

Hello author, how to add display LED to the aime card reader of this project

babyline9210, 2025-01-20:
Hello author, how to add display LED to the aime card reader of this project。
I copied it according to the tutorial, and the effect is very good, but I didn't find the LED status indicator of the AIME card reader. I hope to add the status indicator. There is another problem.
I don't know if it's my problem or something else. It's in mai2.ini. When IgnoreError = 0, the game will prompt 6401 IO error after skipping the SEGA warning screen.

whowechina, 2025-01-20:
I'll look into the cab and aime light support when I'm back from holidays.
I have no clue about the IO error.

whowechina, 2025-02-03:
LEDs are daisy chained, the definition is:
`LED Signal -> 8x [BUTTON LIGHT] - 3x [CAB LIGHT] - 1x [AIME LIGHT]`
Number of LEDs per button light and cab light can be defined by tweak options, max number of LEDs for aime light is fixed to 16 internally.
e6d1f4890bf523c82328b354bfb8782658073fc1

Closed 2025-02-03.

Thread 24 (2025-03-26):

关于Test, Service, Navigate功能键的接线方法以及驱动支持情况

CLDYG7240, 2025-03-26:
作者您好！ 想请您介绍一下Test, Service, Navigate功能键应该要使用什么开关以及什么接线方法进行连接 另外 如果按照上述方法进行了接线 驱动是否直接支持？是否需要自行补丁 非常感谢

whowechina, 2025-03-27:
Test, Service, Navigate, Coin 这几个键对应的 GPIO 是 12, 11, 10, 14，其中 10 和 11 就是那两个 AUX 插座，10 和 14 需要直接从 Pico 板子的引脚上引出。固件本身支持这些键，不需要有额外的东西。
这类问题后面在 Discord 或者 QQ 群里咨询。Issue 主要还是用来汇报缺陷。

Closed 2025-03-27.

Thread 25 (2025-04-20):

How to chain buttons to the end?

shorax, 2025-04-20:
I have now chained the buttons, I can connect to pico controller over the terminal and I see RGB working. But no buttons work, how can I check if i soldered something wrong?  I used this diagram to connect button to the main board

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

This is display command:
mai_pico>display
[RGB]
  Number per button: 1, number per cab: 1
  Key on: c0c0c0, off: 080808
  Level: 127
[Sense]
  Filter: 0, 1, 0
  Sensitivity (global: +0):
     |_1_|_2_|_3_|_4_|_5_|_6_|_7_|_8_|
   A | 0 | 0 | 0 | 0 | 0 | 0 | 0 | 0 |
   B | 0 | 0 | 0 | 0 | 0 | 0 | 0 | 0 |
   C | 0 | 0 |
   D | 0 | 0 | 0 | 0 | 0 | 0 | 0 | 0 |
   E | 0 | 0 | 0 | 0 | 0 | 0 | 0 | 0 |
  Debounce (touch, release): 1, 2
[HID]
  IO4: off, NKRO: key1
[GPIO]
  B1:GP1 B2:GP0 B3:GP4 B4:GP5 B5:GP8 B6:GP9 B7:GP3 B8:GP2
  Test:GP12 Svc:GP11 Nav:GP10 Coin:GP14
[Touch]
     ADDR|_0|_1|_2|_3|_4|_5|_6|_7|_8|_9|10|11|
  0: 0x5a|E3|A2|B2|D2|E2|A1|B1|D1|E1|C2|A8|B8|
  1: 0x5b|D8|E8|A7|B7|D7|E7|A6|B6|D6|E6|A5|B5|
  2: 0x5c|D5|E5|C1|A4|B4|D4|E4|A3|B3|D3|XX|XX|
[AIME]
  NFC Module: Unknown
  Virtual AIC: OFF
  Protocol Mode: 0
[Tweak]
  Main Buttons Active-High: OFF
  Aux Buttons Active-High: OFF

and this is raw:

mai_pico>raw
Touch raw readings:
   Sensor: 0: OK, 1: OK 2: OK
   By Sensor:
   |___1__|___2__|___3__|___4__|___5__|___6__|___7__|___8__|___9__|__10__|__11__|__12__|
 0 |  913 |  910 |  901 |  916 |  915 |  913 |  915 |  907 |  910 |  905 |  903 |  905 |
 1 |  910 |  918 |  912 |  912 |  915 |  919 |  915 |  919 |  918 |  914 |  918 |  913 |
 2 |  913 |  916 |  905 |   14 |   14 |  915 |  914 |  914 |  919 |  910 |  910 |  910 |
   By Zone:
   |___1__|___2__|___3__|___4__|___5__|___6__|___7__|___8__|
 A |  913 |  910 |  914 |   14 |  918 |  915 |  912 |  903 |
 B |  915 |  901 |  919 |   14 |  913 |  919 |  912 |  905 |
 C |  905 |  905 |
 D |  907 |  916 |  910 |  915 |  913 |  918 |  915 |  910 |
 E |  910 |  915 |  913 |  914 |  916 |  914 |  919 |  918 |
mai_pico>raw
Touch raw readings:
   Sensor: 0: OK, 1: OK 2: OK
   By Sensor:
   |___1__|___2__|___3__|___4__|___5__|___6__|___7__|___8__|___9__|__10__|__11__|__12__|
 0 |  912 |  910 |  901 |  917 |  915 |  913 |  915 |  908 |  910 |  906 |  904 |  905 |
 1 |  911 |  918 |  913 |  913 |  915 |  918 |  916 |  920 |  918 |  914 |  918 |  913 |
 2 |  912 |  916 |  905 |   14 |   14 |  915 |  915 |  915 |  919 |  911 |  909 |  910 |
   By Zone:
   |___1__|___2__|___3__|___4__|___5__|___6__|___7__|___8__|
 A |  913 |  910 |  915 |   14 |  918 |  916 |  913 |  904 |
 B |  915 |  901 |  919 |   14 |  913 |  920 |  913 |  905 |
 C |  905 |  906 |
 D |  908 |  917 |  911 |  915 |  912 |  918 |  915 |  911 |
 E |  910 |  915 |  912 |  915 |  916 |  914 |  918 |  918 |

whowechina, 2025-04-21:
Buttons are not chained; each button is connected to an individual GPIO pin. Please check the schematics.

shorax, 2025-04-21:
I did 4 chain you also did in your pictures, then I took the topmost connector and connected it to main board. I can see RGB lightning working, but key presses are not being picked up in game. I dont know how could I test this?

whowechina, 2025-04-21:
Try use hid key mode (not io4) to test buttons.
You can join my Discord server for further questions.

Closed 2025-04-21.

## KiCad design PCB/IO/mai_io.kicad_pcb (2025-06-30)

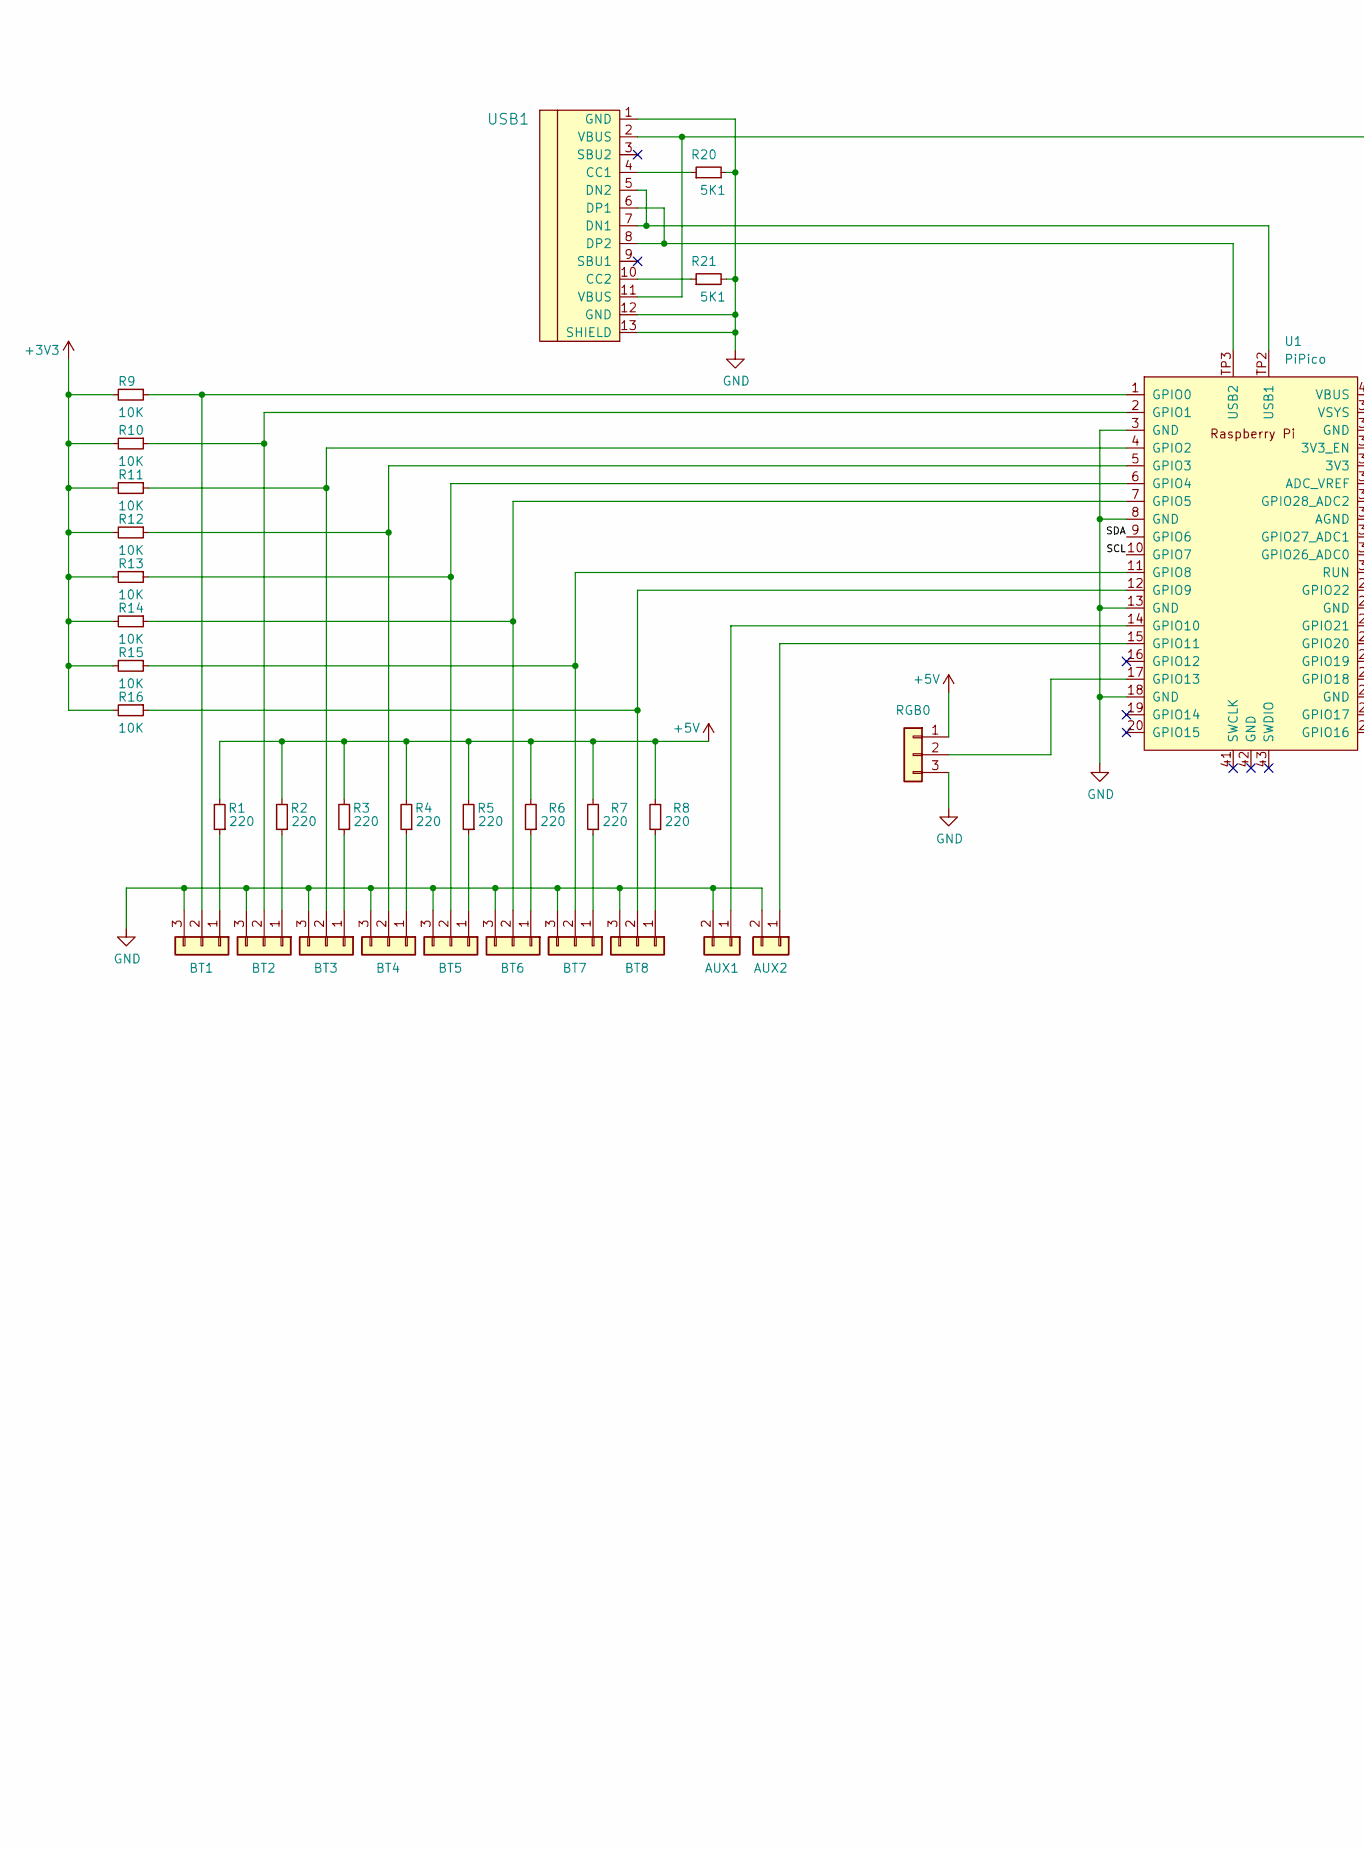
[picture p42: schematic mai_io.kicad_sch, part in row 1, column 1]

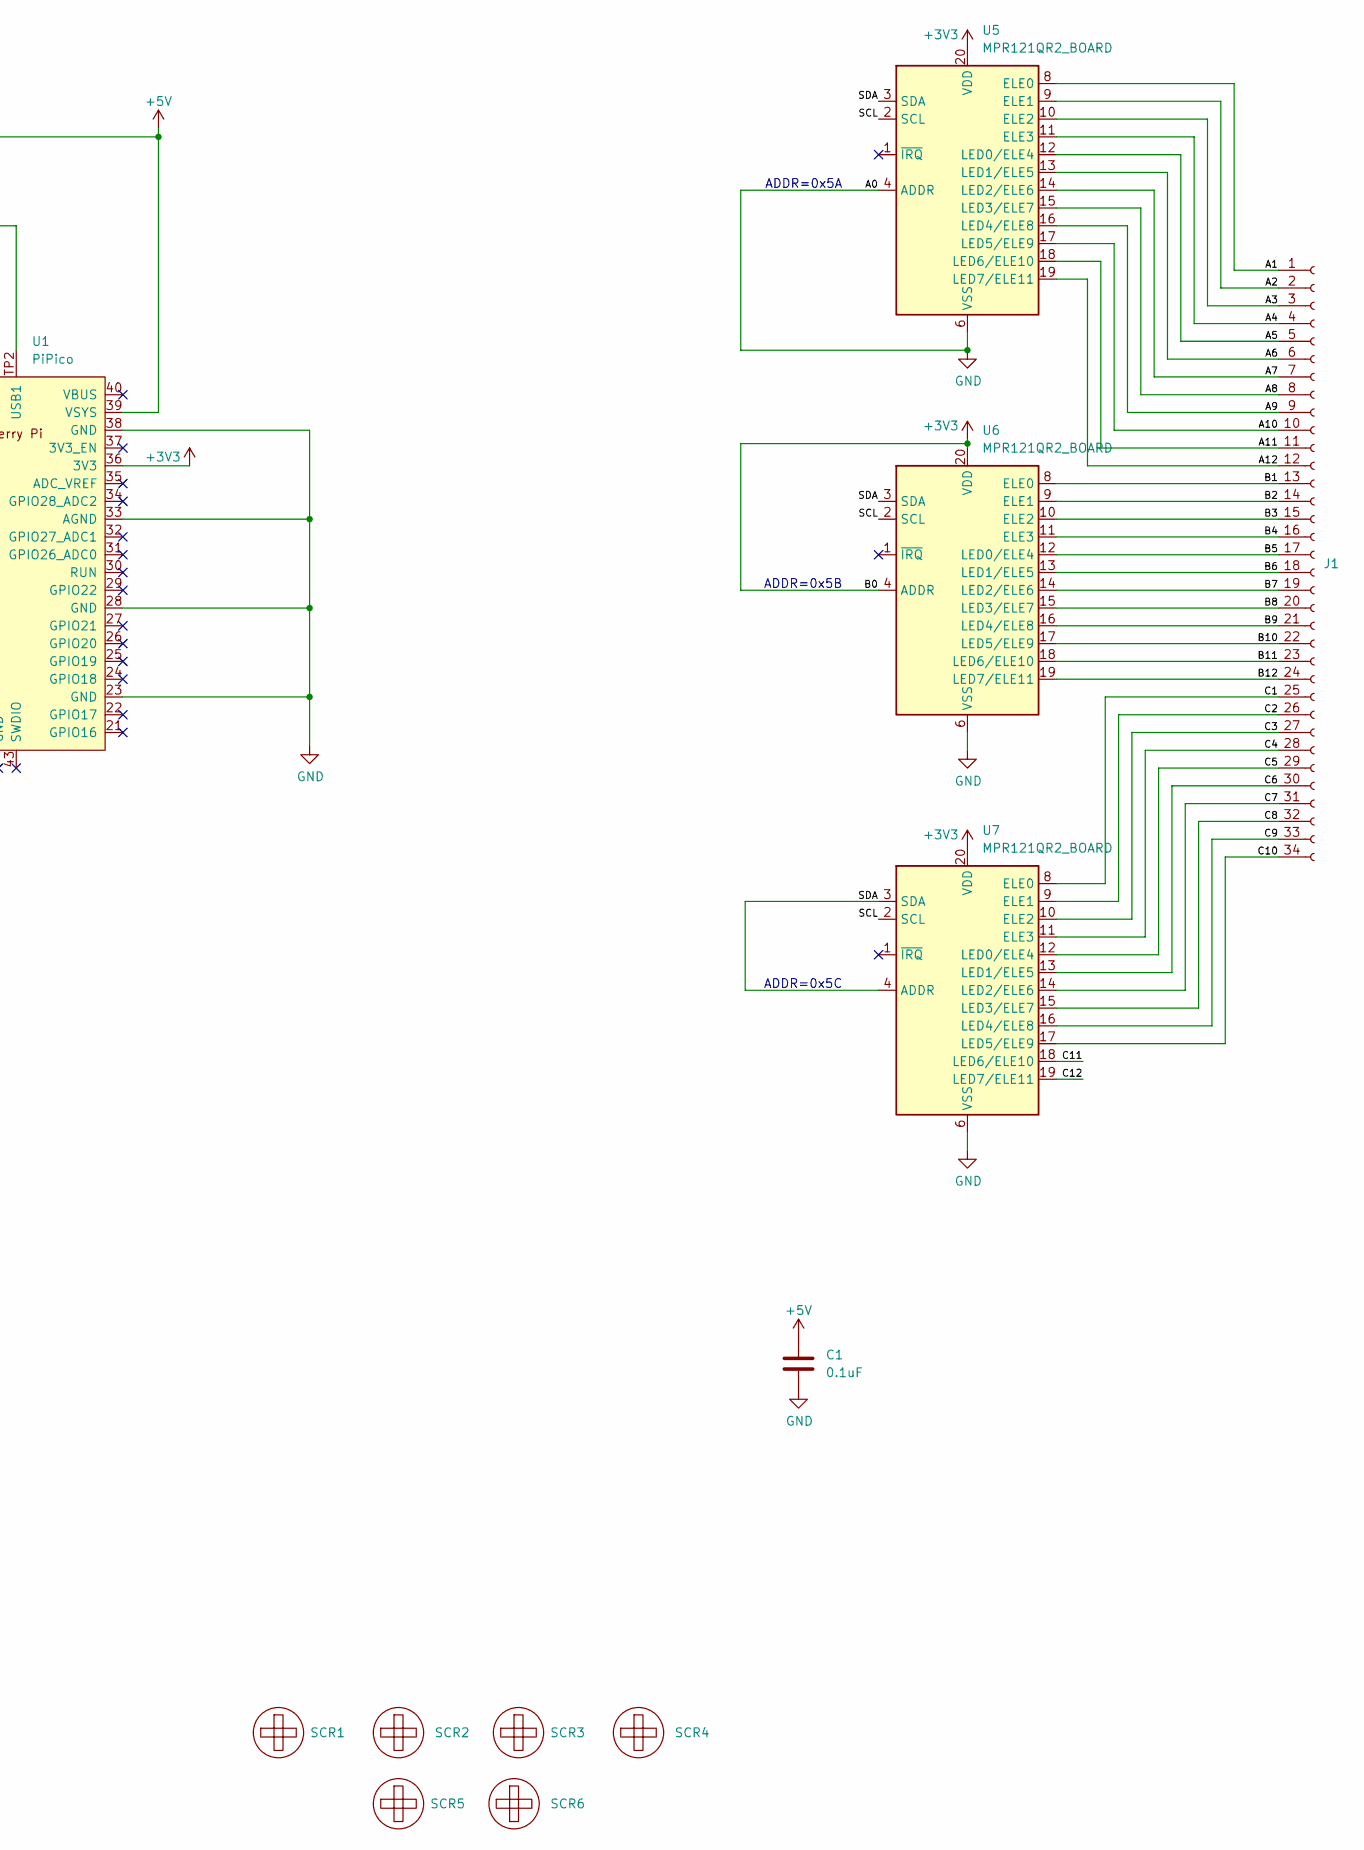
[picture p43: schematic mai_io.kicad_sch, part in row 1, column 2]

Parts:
AUX1, AUX2: Conn_01x02; JST_EH_B2B-EH-A_1x02_P2.50mm_Vertical
BT1, BT2, BT3, BT4, BT5, BT6, BT7, BT8: Conn_01x03; JST_EH_B3B-EH-A_1x03_P2.50mm_Vertical
C1: 0.1uF; C_0603_1608Metric_Pad1.08x0.95mm_HandSolder
J1: Conn_01x34_Female; MaiTouch_Conn34
R1, R2, R3, R4, R5, R6, R7, R8: 220; R_0603_1608Metric_Pad0.98x0.95mm_HandSolder; LCSC C23186
R9, R10, R11, R12, R13, R14, R15, R16: 10K; R_0603_1608Metric_Pad0.98x0.95mm_HandSolder; LCSC C23186
R20, R21: 5K1; R_0603_1608Metric_Pad0.98x0.95mm_HandSolder; LCSC C23186
RGB0: Conn_01x03; JST_EH_B3B-EH-A_1x03_P2.50mm_Vertical
SCR1, SCR2, SCR3, SCR4, SCR5, SCR6: ScrewHole; MountingHole_3.2mm_M3
U1: PiPico; RPi_Pico_SMD_Pins
U5, U6, U7: MPR121QR2_BOARD; MPR121_BOARD
USB1: U262-161N-4BVC11; HRO-TYPE-C-31-M-12-Assembly; LCSC C319148

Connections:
+3V3: R9.2, R10.2, R11.2, R12.2, R13.2, R14.2, R15.2, R16.2, U1.36 (3V3), U5.20 (VDD), U6.4 (ADDR), U6.20 (VDD), U7.20 (VDD)
+5V: C1.1, R1.2, R2.2, R3.2, R4.2, R5.2, R6.2, R7.2, R8.2, RGB0.1, U1.39 (VSYS), USB1.2 (VBUS), USB1.11 (VBUS)
/A1: J1.1, U5.8 (ELE0)
/A2: J1.2, U5.9 (ELE1)
/A3: J1.3, U5.10 (ELE2)
/A4: J1.4, U5.11 (ELE3)
/A5: J1.5, U5.12 (LED0/ELE4)
/A6: J1.6, U5.13 (LED1/ELE5)
/A7: J1.7, U5.14 (LED2/ELE6)
/A8: J1.8, U5.15 (LED3/ELE7)
/A9: J1.9, U5.16 (LED4/ELE8)
/A10: J1.10, U5.17 (LED5/ELE9)
/A11: J1.11, U5.18 (LED6/ELE10)
/A12: J1.12, U5.19 (LED7/ELE11)
/B1: J1.13, U6.8 (ELE0)
/B2: J1.14, U6.9 (ELE1)
/B3: J1.15, U6.10 (ELE2)
/B4: J1.16, U6.11 (ELE3)
/B5: J1.17, U6.12 (LED0/ELE4)
/B6: J1.18, U6.13 (LED1/ELE5)
/B7: J1.19, U6.14 (LED2/ELE6)
/B8: J1.20, U6.15 (LED3/ELE7)
/B9: J1.21, U6.16 (LED4/ELE8)
/B10: J1.22, U6.17 (LED5/ELE9)
/B11: J1.23, U6.18 (LED6/ELE10)
/B12: J1.24, U6.19 (LED7/ELE11)
/C1: J1.25, U7.8 (ELE0)
/C2: J1.26, U7.9 (ELE1)
/C3: J1.27, U7.10 (ELE2)
/C4: J1.28, U7.11 (ELE3)
/C5: J1.29, U7.12 (LED0/ELE4)
/C6: J1.30, U7.13 (LED1/ELE5)
/C7: J1.31, U7.14 (LED2/ELE6)
/C8: J1.32, U7.15 (LED3/ELE7)
/C9: J1.33, U7.16 (LED4/ELE8)
/C10: J1.34, U7.17 (LED5/ELE9)
/C11: U7.18 (LED6/ELE10)
/C12: U7.19 (LED7/ELE11)
/SCL: U1.10 (GPIO7), U5.2 (SCL), U6.2 (SCL), U7.2 (SCL)
/SDA: U1.9 (GPIO6), U5.3 (SDA), U6.3 (SDA), U7.3 (SDA), U7.4 (ADDR)
GND: AUX1.2, AUX2.2, BT1.3, BT2.3, BT3.3, BT4.3, BT5.3, BT6.3, BT7.3, BT8.3, C1.2, R20.2, R21.2, RGB0.3, U1.3 (GND), U1.8 (GND), U1.13 (GND), U1.18 (GND), U1.23 (GND), U1.28 (GND), U1.33 (AGND), U1.38 (GND), U5.4 (ADDR), U5.6 (VSS), U6.6 (VSS), U7.6 (VSS), USB1.1 (GND), USB1.12 (GND), USB1.13 (SHIELD)
unnamed: AUX1.1, U1.14 (GPIO10)
unnamed: AUX2.1, U1.15 (GPIO11)
unnamed: BT1.1, R1.1
unnamed: BT1.2, R9.1, U1.1 (GPIO0)
unnamed: BT2.1, R2.1
unnamed: BT2.2, R10.1, U1.2 (GPIO1)
unnamed: BT3.1, R3.1
unnamed: BT3.2, R11.1, U1.4 (GPIO2)
unnamed: BT4.1, R4.1
unnamed: BT4.2, R12.1, U1.5 (GPIO3)
unnamed: BT5.1, R5.1
unnamed: BT5.2, R13.1, U1.6 (GPIO4)
unnamed: BT6.1, R6.1
unnamed: BT6.2, R14.1, U1.7 (GPIO5)
unnamed: BT7.1, R7.1
unnamed: BT7.2, R15.1, U1.11 (GPIO8)
unnamed: BT8.1, R8.1
unnamed: BT8.2, R16.1, U1.12 (GPIO9)
unnamed: RGB0.2, U1.17 (GPIO13)
unnamed: U1.TP2 (USB1), USB1.5 (DN2), USB1.7 (DN1)
unnamed: U1.TP3 (USB2), USB1.6 (DP1), USB1.8 (DP2)
unnamed: R20.1, USB1.4 (CC1)
unnamed: R21.1, USB1.10 (CC2)

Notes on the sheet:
ADDR=0x5B
ADDR=0x5C
ADDR=0x5A

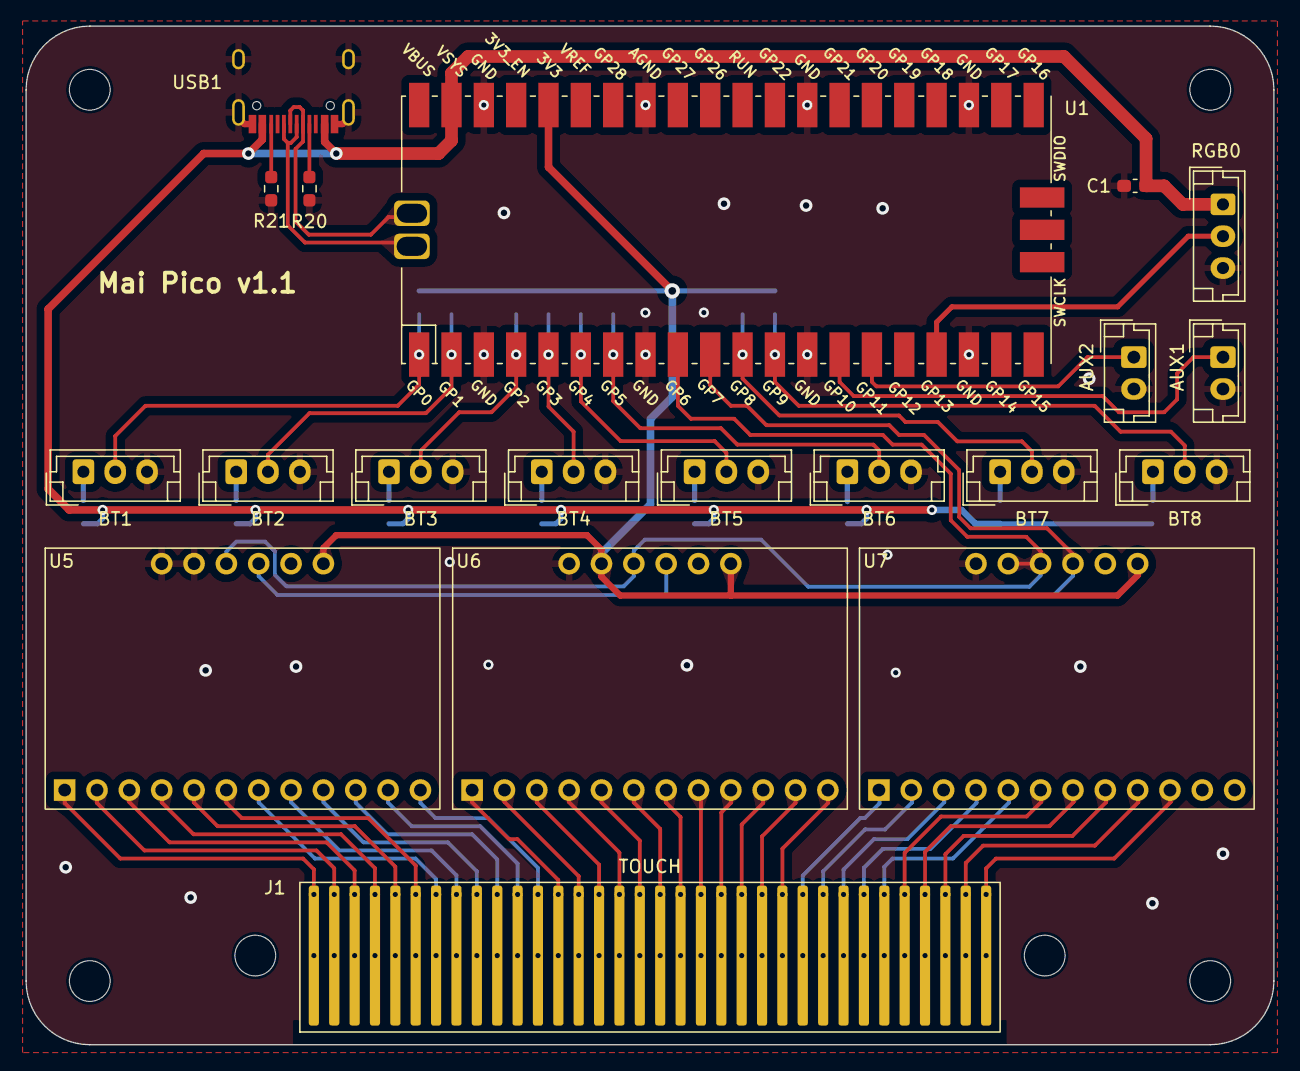
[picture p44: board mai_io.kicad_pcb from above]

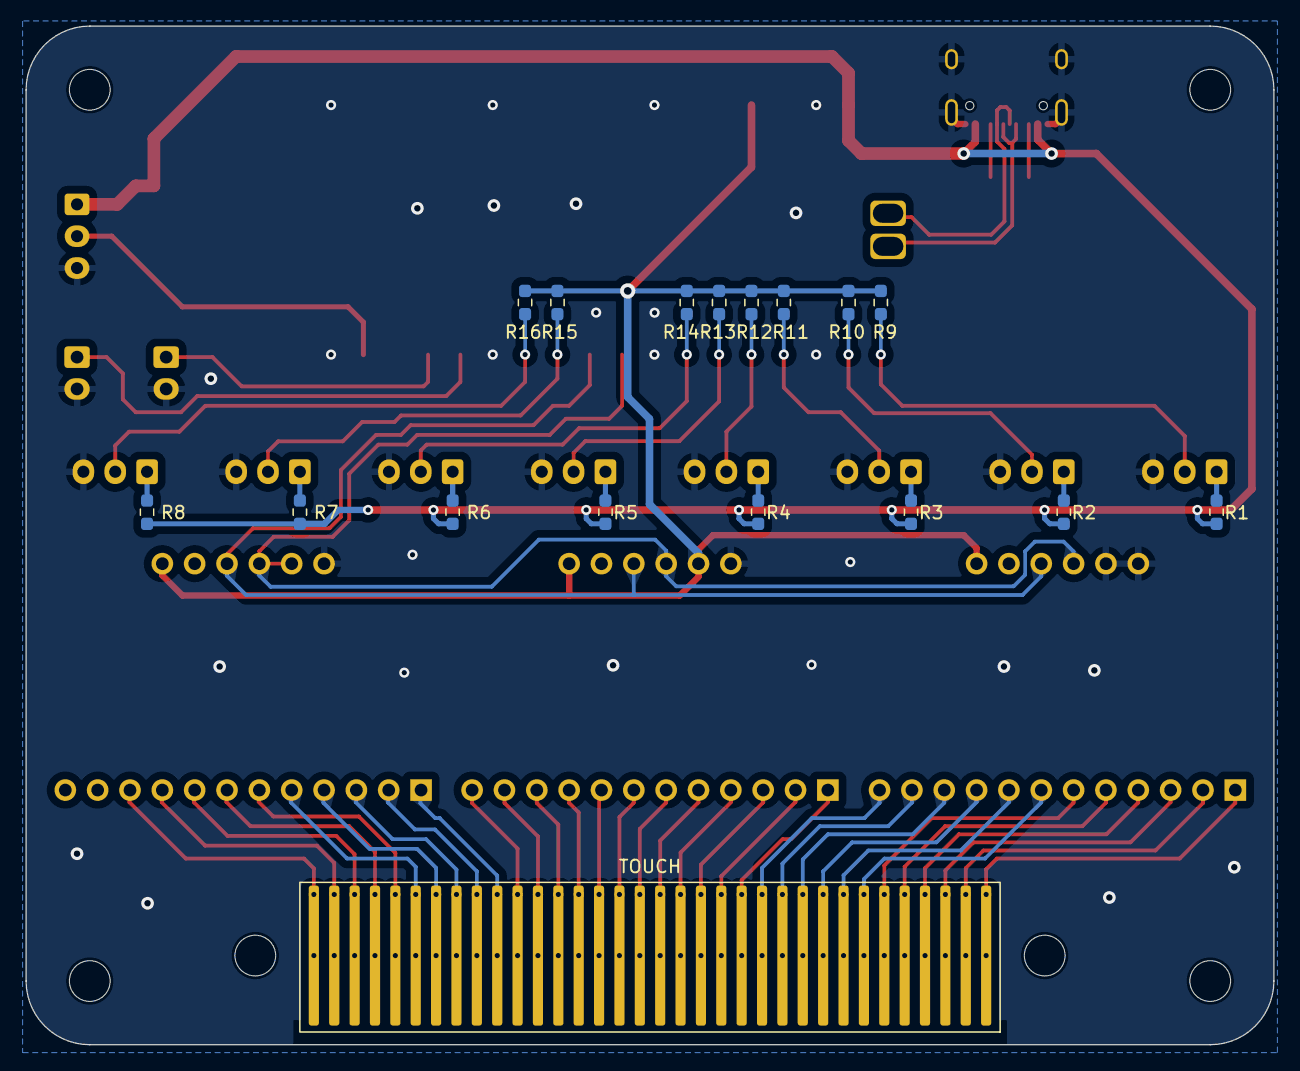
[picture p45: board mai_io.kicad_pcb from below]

Board: 2 copper layers, 98.0 x 80.0 mm, 42 parts (17 on the bottom side), 62 nets.

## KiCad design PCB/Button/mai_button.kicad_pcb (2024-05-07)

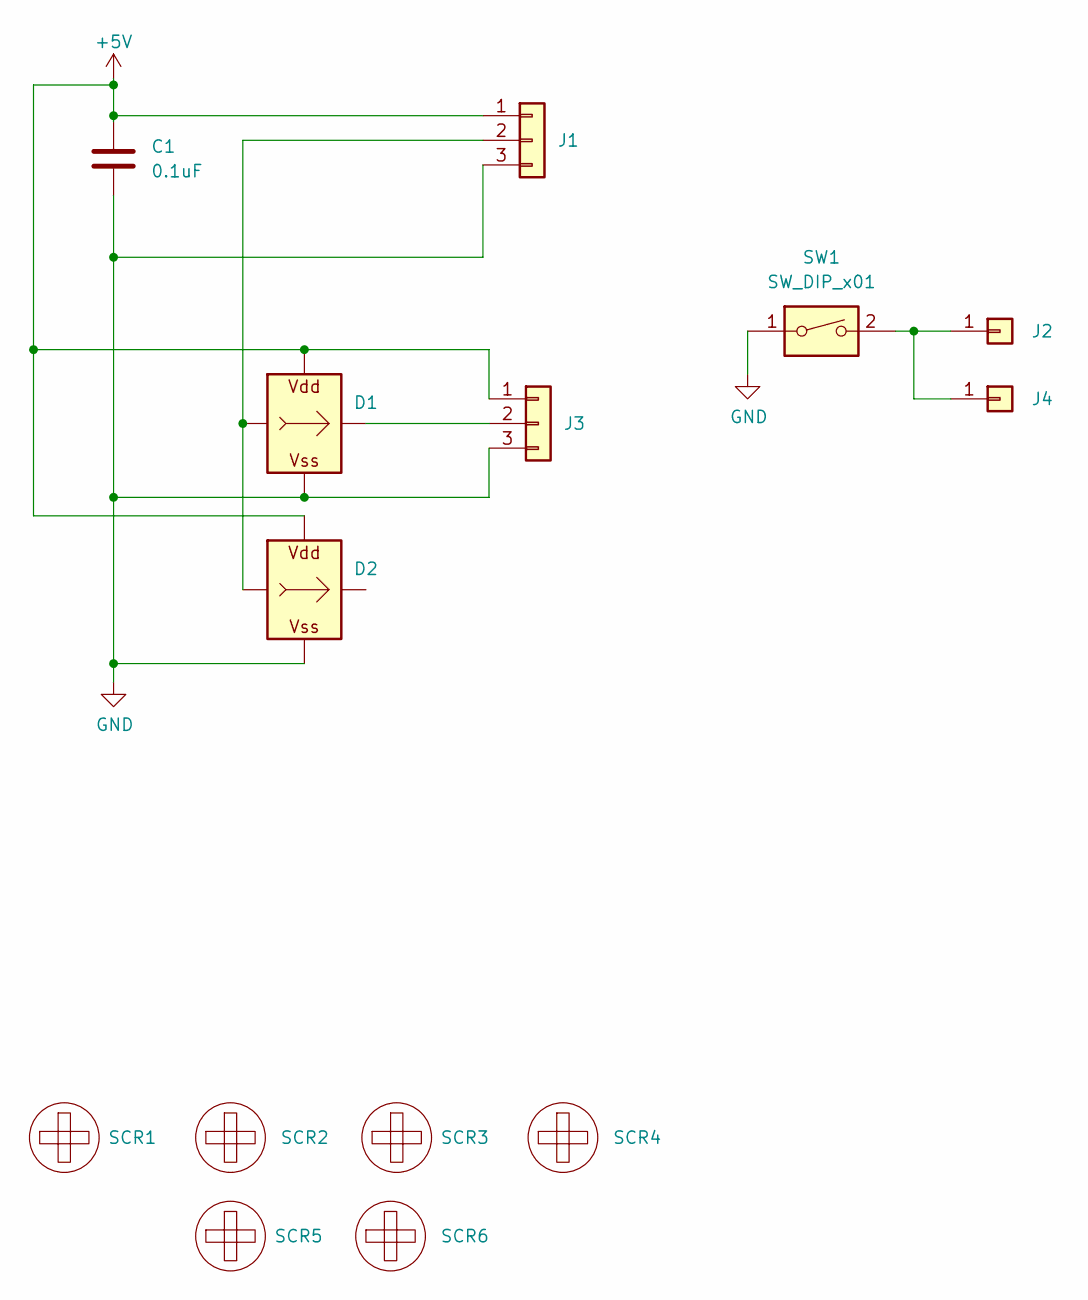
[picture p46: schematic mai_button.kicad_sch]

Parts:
C1: 0.1uF; C_0603_1608Metric_Pad1.08x0.95mm_HandSolder
D1, D2: WS2812B_Unified; WS2812B-2835
J1: RGB In; Solder_3P
J2, J4: Btn; Solder_1P
J3: RGB Out; Solder_3P
SCR1, SCR2, SCR3, SCR4: ScrewHole; Hole2.5
SCR5, SCR6: ScrewHole; Hole4.0
SW1: SW_DIP_x01; SW_Kailh_Choc_V1V2_1.00u_LED

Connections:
+5V: C1.1, D1.V (VDD), D2.V (VDD), J1.1, J3.1
GND: C1.2, D1.G (VSS), D2.G (VSS), J1.3, J3.3, SW1.1
unnamed: D1.I (In), D2.I (In), J1.2
unnamed: D1.O (Out), J3.2
unnamed: J2.1, J4.1, SW1.2

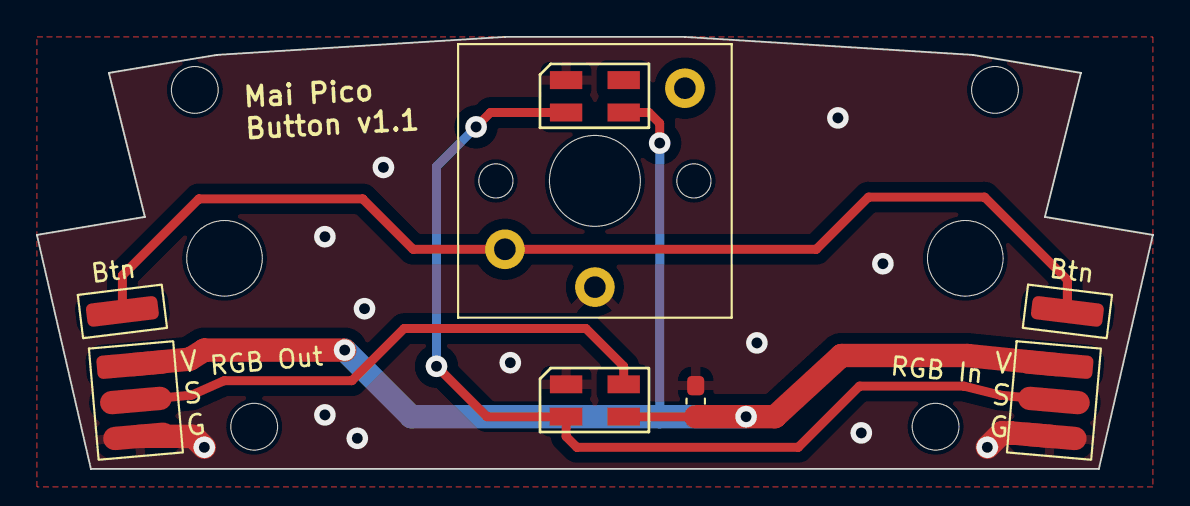
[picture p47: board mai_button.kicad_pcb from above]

Board: 2 copper layers, 62.0 x 24.0 mm, 14 parts (0 on the bottom side), 5 nets.

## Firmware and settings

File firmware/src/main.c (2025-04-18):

/*
 * Controller Main
 * WHowe <github.com/whowechina>
 */

#include <stdlib.h>
#include <stdint.h>
#include <stdbool.h>

#include "pico/stdio.h"
#include "pico/stdlib.h"
#include "bsp/board.h"
#include "pico/multicore.h"
#include "pico/bootrom.h"

#include "hardware/clocks.h"
#include "hardware/gpio.h"
#include "hardware/sync.h"
#include "hardware/structs/ioqspi.h"
#include "hardware/structs/sio.h"

#include "tusb.h"
#include "usb_descriptors.h"

#include "aime.h"
#include "nfc.h"

#include "board_defs.h"

#include "touch.h"
#include "button.h"
#include "rgb.h"

#include "save.h"
#include "config.h"
#include "cli.h"
#include "commands.h"
#include "io.h"
#include "hid.h"

static void button_lights_clear()
{
    for (int i = 0; i < 8; i++) {
        rgb_set_button(i, 0, 0);
    }
}

static void button_lights_rainbow()
{
    static uint16_t loop = 0;
    loop++;
    uint16_t buttons = button_read();
    for (int i = 0; i < 8; i++) {
        uint8_t phase = (i * 256 + loop) / 8;
        uint32_t color;
        if (buttons & (1 << i)) {
            color = rgb32_from_hsv(phase, 64, 255);
        } else {
            color = rgb32_from_hsv(phase, 240, 20);
        }
        rgb_set_button(i, color, 0);
    }
}

static void run_lights()
{
    static bool was_rainbow = true;
    bool go_rainbow = !io_is_active() && !aime_is_active();

    if (go_rainbow) {
        button_lights_rainbow();
    } else if (was_rainbow) {
        button_lights_clear();
    }

    was_rainbow = go_rainbow;

    rgb_set_aime(aime_led_color());
}

const int aime_intf = 3;
static void cdc_aime_putc(uint8_t byte)
{
    tud_cdc_n_write(aime_intf, &byte, 1);
    tud_cdc_n_write_flush(aime_intf);
}

static void aime_run()
{
    if (tud_cdc_n_available(aime_intf)) {
        uint8_t buf[32];
        uint32_t count = tud_cdc_n_read(aime_intf, buf, sizeof(buf));
        for (int i = 0; i < count; i++) {
            aime_feed(buf[i]);
        }
    }
}

static mutex_t core1_io_lock;
static void core1_loop()
{
    while (1) {
        if (mutex_try_enter(&core1_io_lock, NULL)) {
            run_lights();
            rgb_update();
            mutex_exit(&core1_io_lock);
        }
        cli_fps_count(1);
        sleep_ms(1);
    }
}

static void runtime_ctrl()
{
    /* Just use long-press COIN to reset touch in runtime */
    static bool applied = false;
    static uint64_t press_time = 0;
    static bool last_coin_button = false;
    bool coin_button = button_read() & (1 << 11);

    if (coin_button) {
        if (!last_coin_button) {
            press_time = time_us_64();
            applied = false;
        }
        if (!applied && (time_us_64() - press_time > 2000000)) {
            touch_sensor_init();
            applied = true;
        }
    }

    last_coin_button = coin_button;
}

static void main_frame()
{
    static uint64_t next_frame = 0;

    sleep_until(next_frame);
    next_frame += 1000;

    tud_task();
    io_update();

    cli_run();

    touch_update();
    button_update();

    hid_update();

    cli_fps_count(0);
}

static void core0_loop()
{
    while(1) {
        main_frame();

        aime_run();
        save_loop();
        runtime_ctrl();
    }
}

void init()
{
    sleep_ms(50);
    set_sys_clock_khz(150000, true);
    board_init();

    tusb_init();
    stdio_init_all();

    config_init();
    mutex_init(&core1_io_lock);

    save_init(board_id_32() ^ 0xcafe1111, &core1_io_lock);

    if (!mai_cfg->hid.io4) {
        usb_descriptors_disable_io4();
    }

    touch_init();
    button_init();
    rgb_init();

    nfc_attach_i2c(I2C_PORT);
    nfc_init();
    nfc_set_wait_loop(main_frame);
    aime_init(cdc_aime_putc);
    aime_sub_mode(mai_cfg->aime.mode);
    aime_virtual_aic(mai_cfg->aime.virtual_aic);

    cli_init("mai_pico>", "\n   << Mai Pico Controller >>\n"
                            " https://github.com/whowechina\n\n");
    commands_init();

    mai_runtime.key_stuck = button_is_stuck();
}

int main(void)
{
    init();
    multicore_launch_core1(core1_loop);
    core0_loop();
    return 0;
}

// Invoked when received GET_REPORT control request
// Application must fill buffer report's content and return its length.
// Return zero will cause the stack to STALL request
uint16_t tud_hid_get_report_cb(uint8_t itf, uint8_t report_id,
                               hid_report_type_t report_type, uint8_t *buffer,
                               uint16_t reqlen)
{
    printf("Get from USB %d-%d\n", report_id, report_type);
    return 0;
}

// Invoked when received SET_REPORT control request or
// received data on OUT endpoint ( Report ID = 0, Type = 0 )
void tud_hid_set_report_cb(uint8_t itf, uint8_t report_id,
                           hid_report_type_t report_type, uint8_t const *buffer,
                           uint16_t bufsize)
{
    hid_proc(buffer, bufsize);
}

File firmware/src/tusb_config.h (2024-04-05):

/*
 * The MIT License (MIT)
 *
 * Copyright (c) 2019 Ha Thach (tinyusb.org)
 *
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
 */

#ifndef _TUSB_CONFIG_H_
#define _TUSB_CONFIG_H_

#ifdef __cplusplus
extern "C" {
#endif

//--------------------------------------------------------------------
// COMMON CONFIGURATION
//--------------------------------------------------------------------

// defined by board.mk
#ifndef CFG_TUSB_MCU
#error CFG_TUSB_MCU must be defined
#endif

// RHPort number used for device can be defined by board.mk, default to port 0
#ifndef BOARD_DEVICE_RHPORT_NUM
#define BOARD_DEVICE_RHPORT_NUM 0
#endif

// RHPort max operational speed can defined by board.mk
// Default to Highspeed for MCU with internal HighSpeed PHY (can be port
// specific), otherwise FullSpeed
#ifndef BOARD_DEVICE_RHPORT_SPEED
#if (CFG_TUSB_MCU == OPT_MCU_LPC18XX || CFG_TUSB_MCU == OPT_MCU_LPC43XX ||   \
     CFG_TUSB_MCU == OPT_MCU_MIMXRT10XX || CFG_TUSB_MCU == OPT_MCU_NUC505 || \
     CFG_TUSB_MCU == OPT_MCU_CXD56)
#define BOARD_DEVICE_RHPORT_SPEED OPT_MODE_HIGH_SPEED
#else
#define BOARD_DEVICE_RHPORT_SPEED OPT_MODE_FULL_SPEED
#endif
#endif

// Device mode with rhport and speed defined by board.mk
#if BOARD_DEVICE_RHPORT_NUM == 0
#define CFG_TUSB_RHPORT0_MODE (OPT_MODE_DEVICE | BOARD_DEVICE_RHPORT_SPEED)
#elif BOARD_DEVICE_RHPORT_NUM == 1
#define CFG_TUSB_RHPORT1_MODE (OPT_MODE_DEVICE | BOARD_DEVICE_RHPORT_SPEED)
#else
#error "Incorrect RHPort configuration"
#endif

#ifndef CFG_TUSB_OS
#define CFG_TUSB_OS OPT_OS_NONE
#endif

// CFG_TUSB_DEBUG is defined by compiler in DEBUG build
// #define CFG_TUSB_DEBUG           0

/* USB DMA on some MCUs can only access a specific SRAM region with restriction
 * on alignment. Tinyusb use follows macros to declare transferring memory so
 * that they can be put into those specific section. e.g
 * - CFG_TUSB_MEM SECTION : __attribute__ (( section(".usb_ram") ))
 * - CFG_TUSB_MEM_ALIGN   : __attribute__ ((aligned(4)))
 */
#ifndef CFG_TUSB_MEM_SECTION
#define CFG_TUSB_MEM_SECTION
#endif

#ifndef CFG_TUSB_MEM_ALIGN
#define CFG_TUSB_MEM_ALIGN __attribute__((aligned(4)))
#endif

//--------------------------------------------------------------------
// DEVICE CONFIGURATION
//--------------------------------------------------------------------

#ifndef CFG_TUD_ENDPOINT0_SIZE
#define CFG_TUD_ENDPOINT0_SIZE 64
#endif

//------------- CLASS -------------//
#define CFG_TUD_HID 2
#define CFG_TUD_CDC 4
#define CFG_TUD_MSC 0
#define CFG_TUD_MIDI 0
#define CFG_TUD_VENDOR 0

// HID buffer size Should be sufficient to hold ID (if any) + Data
#define CFG_TUD_HID_EP_BUFSIZE 64

#define CFG_TUD_VENDOR            0

// HID buffer size Should be sufficient to hold ID (if any) + Data
#define CFG_TUD_HID_EP_BUFSIZE    64

// CDC FIFO size of TX and RX
#define CFG_TUD_CDC_RX_BUFSIZE   (TUD_OPT_HIGH_SPEED ? 512 : 128)
#define CFG_TUD_CDC_TX_BUFSIZE   (TUD_OPT_HIGH_SPEED ? 512 : 128)

// CDC Endpoint transfer buffer size, more is faster
#define CFG_TUD_CDC_EP_BUFSIZE   (TUD_OPT_HIGH_SPEED ? 512 : 128)

#ifdef __cplusplus
}
#endif

#endif /* _TUSB_CONFIG_H_ */

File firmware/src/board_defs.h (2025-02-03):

/*
 * Mai Controller Board Definitions
 * WHowe <github.com/whowechina>
 */

#if defined BOARD_MAI_PICO

#define I2C_PORT i2c1
#define I2C_SDA 6
#define I2C_SCL 7
#define I2C_FREQ 400*1000

#define RGB_PIN 13
#define RGB_ORDER GRB // or RGB
#define RGB_BUTTON_MAP { 5, 4, 3, 2, 1, 0, 7, 6 }

/* 8 main buttons, Test, Service, Navigate, Coin */
#define BUTTON_DEF { 1, 0, 4, 5, 8, 9, 3, 2, 12, 11, 10, 14 }

/* HID Keycode: https://github.com/hathach/tinyusb/blob/master/src/class/hid/hid.h */
// P1: WEDCXZAQ3(F1)(F2)(F3) P2: (Numpad)89632147*(F1)(F2)(F3)
#define BUTTON_NKRO_MAP_P1 "\x1a\x08\x07\x06\x1b\x1d\x04\x14\x20\x3a\x3b\x3c"
#define BUTTON_NKRO_MAP_P2 "\x60\x61\x5e\x5b\x5a\x59\x5c\x5f\x55\x3a\x3b\x3c"

#define TOUCH_MAP { E3, A2, B2, D2, E2, A1, B1, D1, E1, C2, A8, B8, \
                    D8, E8, A7, B7, D7, E7, A6, B6, D6, E6, A5, B5, \
                    D5, E5, C1, A4, B4, D4, E4, A3, B3, D3, XX, XX }
#else

#endif

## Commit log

2023-09-24 Firmware copied from chu pico
2023-10-10 Use pico's board id as USB SN
2023-10-13 USB cleanup and nkro loss issue fixed.
    [button.c, commands.c, main.c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]
2023-10-14 3D print and CAD files update
    [mai_cover.stl, mai_link.stl, mai_pico_ito_v1.dwg]
2023-10-14 Remove duplicated dwg file
    [maimai_touch v53_v1.dwg]
2023-11-26 RGB LED number configurable (not tested)
2023-11-26 RGB num per button (if not work, use earlier UF2)
2023-12-08 Fixed touch update not fast enough issue
    [button.c]
2023-12-09 Button via IO4 Support
2024-02-13 Button GPIOs can be re-assigned thru CLI
2024-02-16 Fix button read bug introduced in earlier commit
    [button.c]
2024-02-17 Extra buttons working in nkro mode: select/test/service/coin
2024-02-17 Fix LED bahavior
2024-02-18 Optimize Touch and LED log prints
2024-02-25 IO4 output implemented and coin button working
2024-02-25 Switch language easier
2024-03-09 LED I/O can pass self-test
2024-03-09 Max electrode charge for better sense (test)
2024-03-23 Display sensor status in raw command
2024-04-04 Integrating AIC pico library
2024-04-29 Suppress nkro when button stuck
    [button.c, commands.c, main.c]
2024-05-07 Button PCB update (v1.1)
    [mai_button.kicad_pcb, mai_button.kicad_sch]
2024-05-07 Minor button PCB update (so v1.11)
2024-06-18 Acitve-high button switches as a tweak options
2024-07-15 Cross-reference to new Groove Pico
2024-09-14 Feature: raw command with individual sensor readings and zone readings
2024-09-15 Fix: Use dependent buffer as readout buffer, then copy to readout array
    [board_defs.h, touch.c]
2024-09-16 Revert: Remove accidential modification on board_defs
    [board_defs.h]
2024-09-16 Fix: Minor update on function signature
    [touch.c]
2024-09-18 IO4 can be turned off (to live with official IO4 board)
2024-11-13 Cross-reference to Ju Pico
2024-11-29 Runtime touch reset with long-press COIN button
    [main.c, touch.c]
2024-12-26 Cross-link to bishi pico and readme re-arrangerment
2025-02-03 Sync to latest aic pico library
2025-02-03 Fix MPR121 filter setting bug
    [commands.c]
2025-04-04 Cross-reference to Nos Pico
2025-06-30 IO board v1.1 (better support for arcade buttons and simplified)
    [mai_io.kicad_pcb, mai_io.kicad_sch]
2025-06-30 Update readme to match IO PCB v1.1
2025-08-03 Fix io4 button mapping
